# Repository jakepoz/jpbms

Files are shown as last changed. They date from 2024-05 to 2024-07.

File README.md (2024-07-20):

**JPBms**

JPBms is a simple BMS for solar charging and balancing a 3-cell lithium ion battery.

The key thing about it is that it uses no custom ICs, beyond a basic microcontroller. 
That is to say that it depends on no hard-to-find custom ICs that will be obsolete 3 years from now.
It implements a basic charging circuit that can charge a ~12V 3S battery from basically any input power source between
6V-24V, including if that source is a solar panel.

-------------------------------



[v1.3 Schematics](JPBms2-v1.3.pdf)

-----------------------------
- STM32L053 microcontroller
- It's just an inductor with a full set of switches on it, so you can customize it
- Simple resistive balancing
- Single layer board design for easy JLCPCB style production
  - ~$150 to order 5 from JLCPCB, way cheaper in bulk
- Low ~100uA quiescent current
- XT30 solar panel connector, JST-XH battery balance connector

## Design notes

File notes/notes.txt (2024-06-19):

Version 1.3 stuff:
 - The 10M pullup calculation was clearly wrong, voltage only gets up to around 1.25V out of 2.5, so not above the .7 Vdd it should be to be reliable.
   Do I even need the pullup, what's the leakage on the internal one? Better do some real measurements and find out
 - I should have specced 0.5% resistors on the VBATT stuff, or something more precise there in general...

Gate bounce:
 - I'm seeing this effect where, I charge up the inductor via VSolar (off of power supply for now)
 - There is definitely current in the inductor, because then I briefly enable VBatt + GND on the other side, and then turn those gates off again
 - and I see the spike in voltage where the inductor goes just above VBATT charging it
 - but then, the inductor current shrinks, and there is a big osilation.
 - And you see the high side gates of the mosfets take on the same oscillating waveform

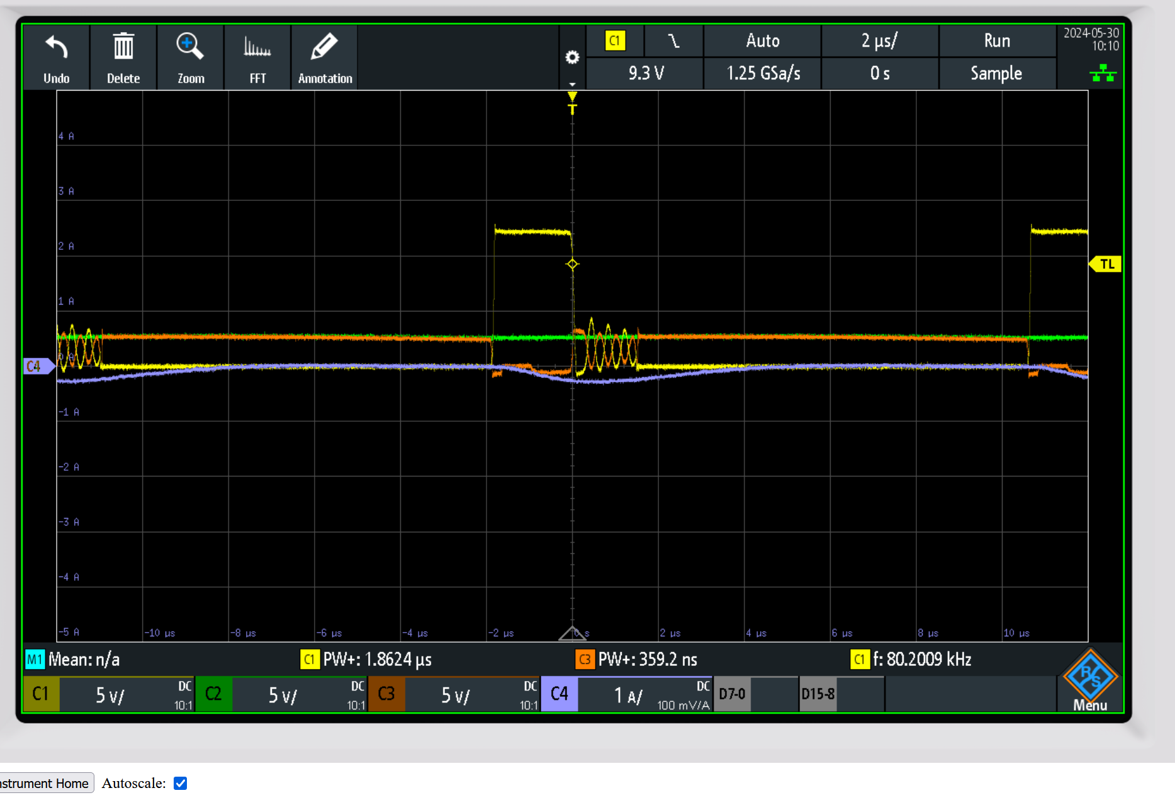
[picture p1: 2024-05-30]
notes/Gate bounce reduced with larger side A time, almost continuous.PNG

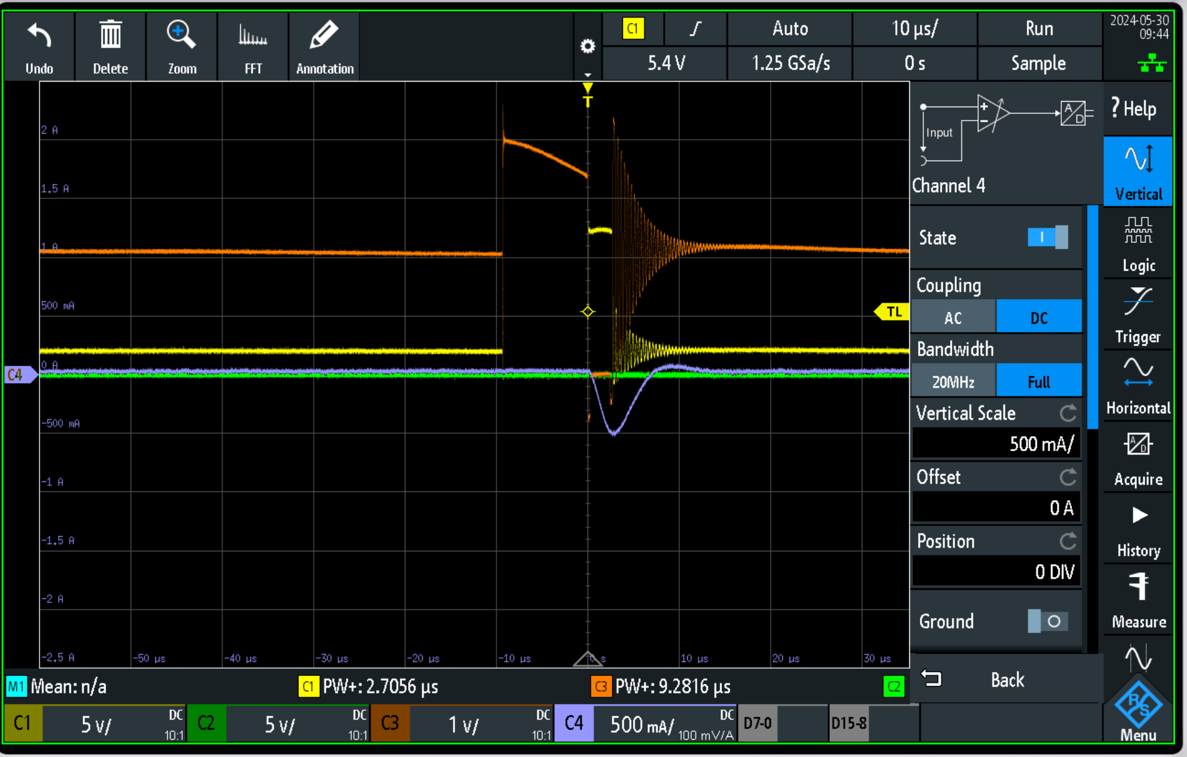
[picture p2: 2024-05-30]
notes/Gate bounce.PNG

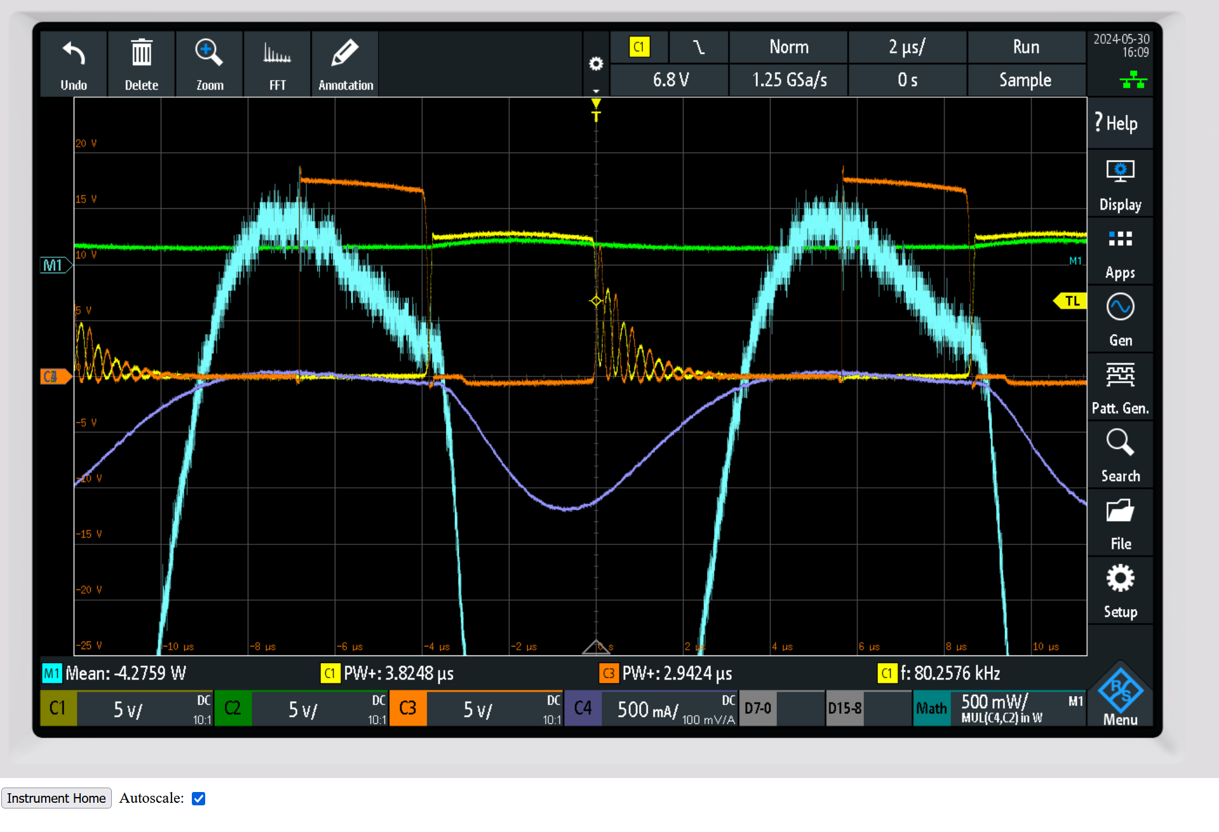
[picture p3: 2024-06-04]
notes/Charging 4.2watts.PNG

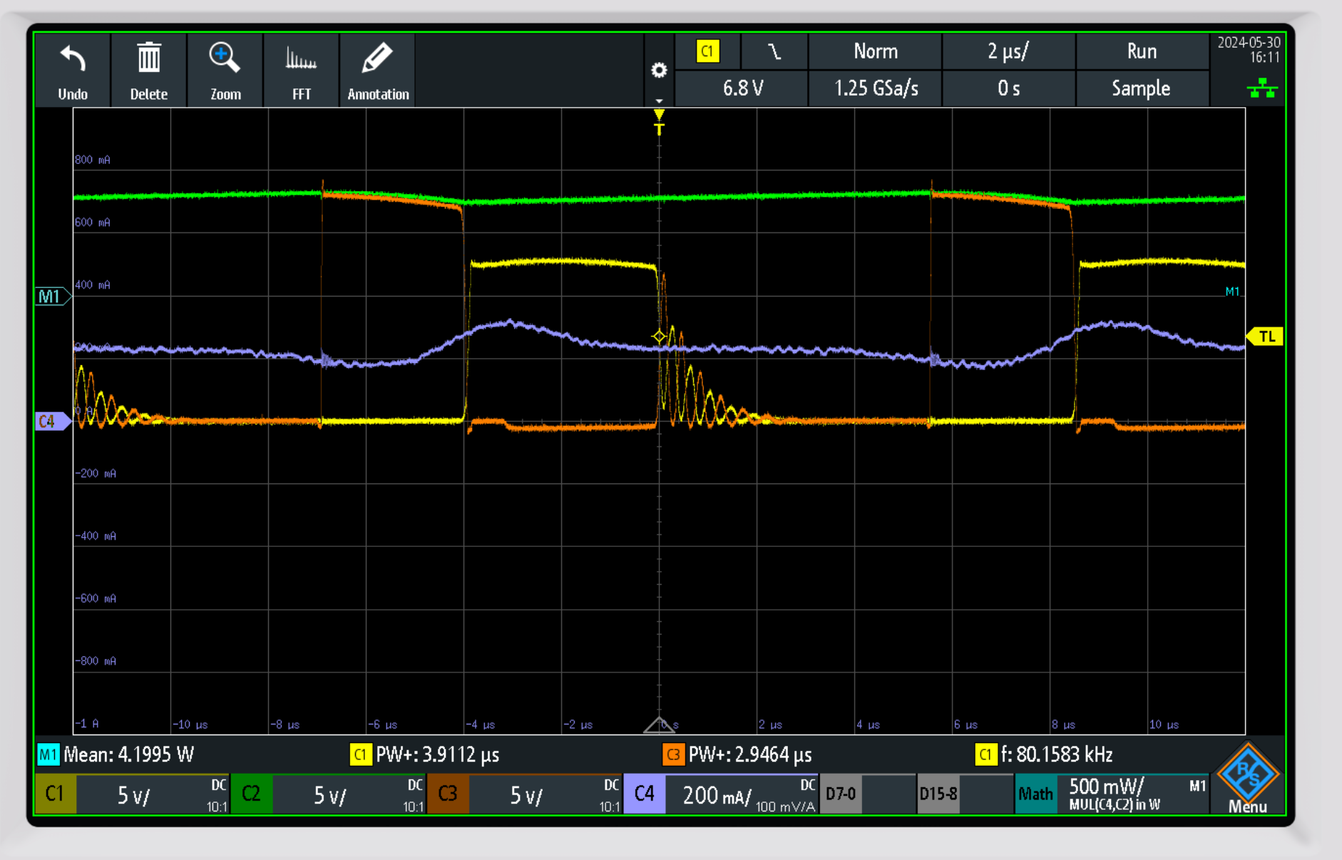
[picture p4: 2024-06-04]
notes/Solar panel current vs voltage.PNG

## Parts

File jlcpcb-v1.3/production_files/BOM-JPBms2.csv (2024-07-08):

Comment | Designator | Footprint | LCSC
LED_G | D4 | LED_0603_1608Metric | C12624
10u | C2,C3,C4,C8 | C_1206_3216Metric | C13585
.1u | C10,C11,C12,C13,C14,C17,C21,C22,C7,C9 | C_0603_1608Metric | C14663
AO3401A | Q21,Q5,Q6,Q7 | SOT-23 | C15127
Conn_01x04 JST-XH | BAL1 | JST_XH_S4B-XH-A_1x04_P2.50mm_Horizontal_Tight | C157925
1u | C15,C16,C19,C20 | C_0603_1608Metric | C15849
10p | C1 | C_0603_1608Metric | C1634
100 | R28,R29,R30 | R_1206_3216Metric | C17901
AO3400A | Q1,Q2,Q3,Q4 | SOT-23 | C20917
1k | R22,R23,R24,R33,R46,R50,R53 | R_0603_1608Metric | C21190
LED_R | D6 | LED_0603_1608Metric | C2286
LED_Y | D11,D12,D13,D5 | LED_0603_1608Metric | C2287
1M | R10,R11,R19,R20,R21,R25,R26,R27,R34,R35,R38,R40,R44,R45,R47,R49,R51,R52,R54,R8,R9 | R_0603_1608Metric | C22935
2k | R4 | R_0603_1608Metric | C22975
4.7k | R2,R37 | R_0603_1608Metric | C23162
56k | R36 | R_0603_1608Metric | C23206
Conn_01x04 Picoblade | UART1 | Molex_PicoBlade_53398-0471_1x04-1MP_P1.25mm_Vertical | C234195
L6388E | U4,U6 | SO-8_3.9x4.9mm_P1.27mm | C23921
150 | R12,R13,R14,R31,R32,R41,R42,R43 | R_0402_1005Metric | C25082
18k | R5 | R_0603_1608Metric | C25810
10M | R39 | R_0603_1608Metric | C26097
ST715M25R | U2 | SOT-23-5 | C2832805
0.1 | R3 | R_1206_3216Metric | C2903496
SW_Push | SW1 | SW_Push_1P1T_XKB_TS-1187A | C318884
47uH | L1 | L_Sunlord_MWSA0605S | C408471
3k | R1 | R_0603_1608Metric | C4211
75 | R15,R16,R17,R18,R48,R55,R56 | R_0603_1608Metric | C4275
XT30PW-M | J1 | AMASS_XT30PW-M_1x02_P2.50mm_Horizontal | C431092
SMAJ30CA | D14 | D_SMA | C5249596
7500 | R6 | R_0603_1608Metric | C728597
2N7002 | Q10,Q13,Q16,Q19,Q20,Q8,Q9 | SOT-323_SC-70 | C7420322
H5VL10B | D7,D8 | D_SOD-882 | C7420372
STM32L053R8Tx | U3 | LQFP-64_10x10mm_P0.5mm | C784738
BAT54SW | D1,D18,D2,D3 | SOT-323_SC-70 | C78606
ZXCT1107 | U1 | SOT-23 | C82766
1600 | R7 | R_0603_1608Metric | C861205
47u | C5 | C_1206_3216Metric | C96123
SK2301AW | Q11,Q12,Q14,Q15,Q17,Q18 | SOT-323_SC-70 | C962722
30V 750mA | F1,F2,F3 | Fuse_1206_3216Metric | C976305
+BATT | TP2 | TestPoint_Loop_D2.60mm_Drill1.6mm_Beaded
TestPoint | TP6 | TestPoint_Loop_D2.60mm_Drill1.6mm_Beaded
GND | TP1 | TestPoint_Loop_D2.60mm_Drill1.6mm_Beaded
TestPoint | TP5 | TestPoint_Loop_D2.60mm_Drill1.6mm_Beaded
SMAJ16A | D9 | D_SMA

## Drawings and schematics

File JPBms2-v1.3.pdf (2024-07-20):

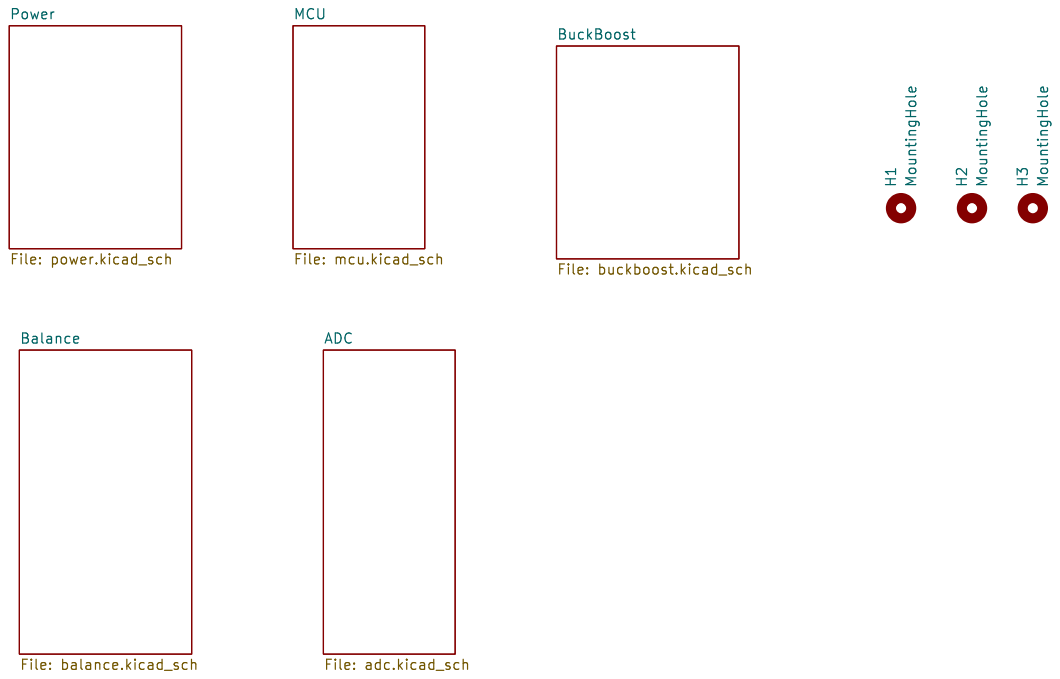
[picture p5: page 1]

Id: 1/6 Title: File: JPBms2.kicad_sch Sheet: /

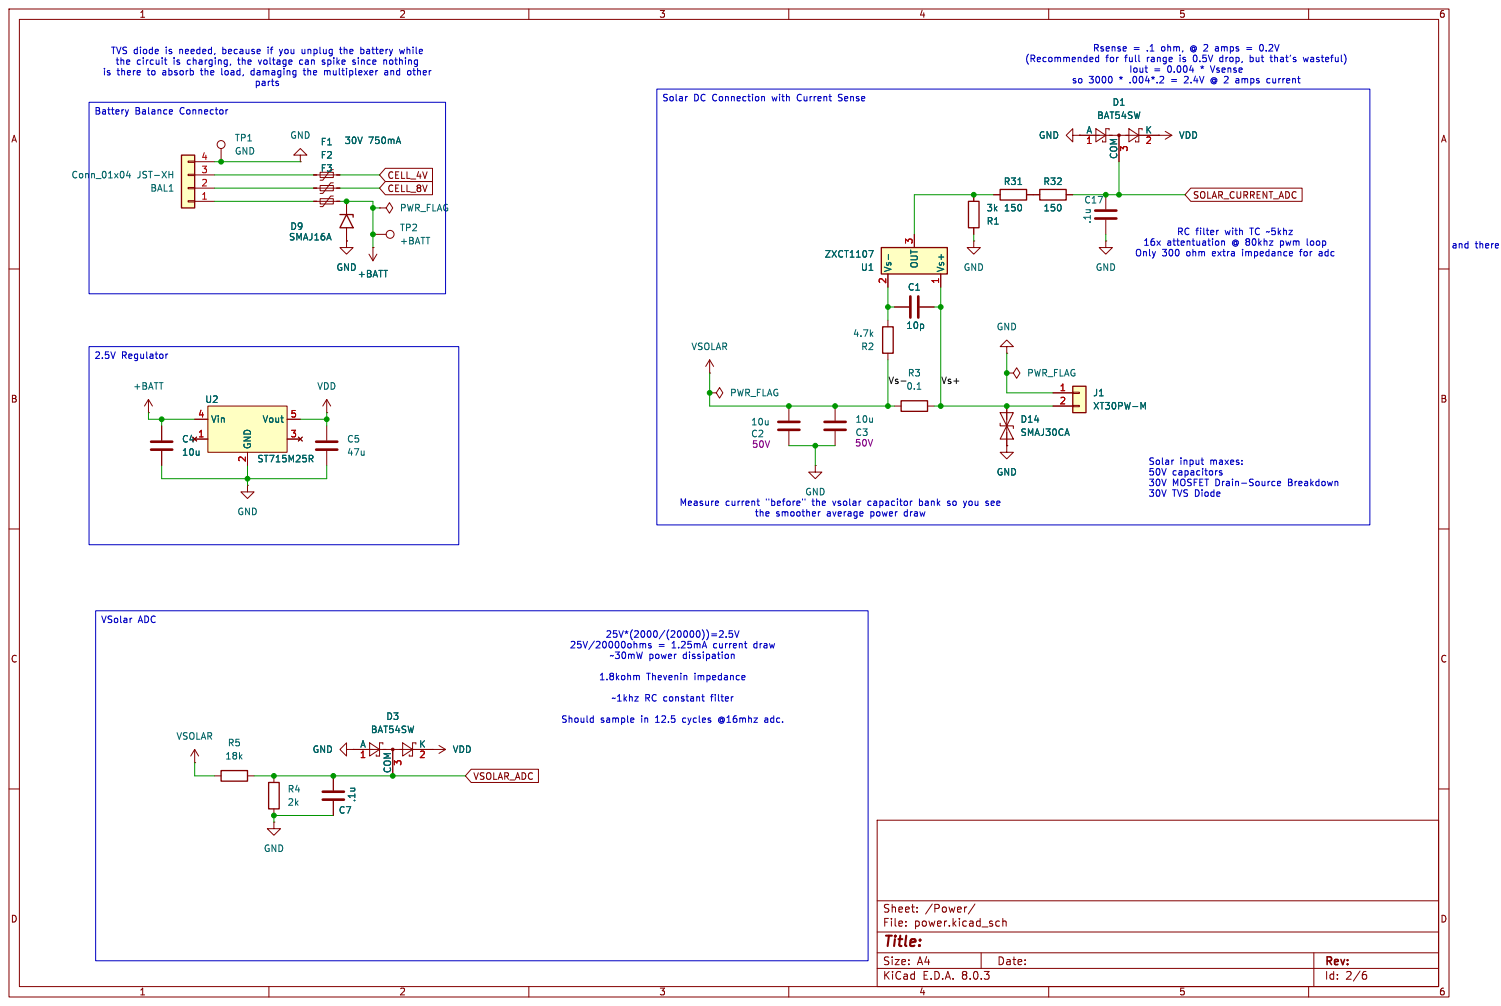
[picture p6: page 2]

Battery Balance Connector 2.5V Regulator VSolar ADC

Id: 2/6 Title: File: power.kicad_sch Sheet: /Power/ R5

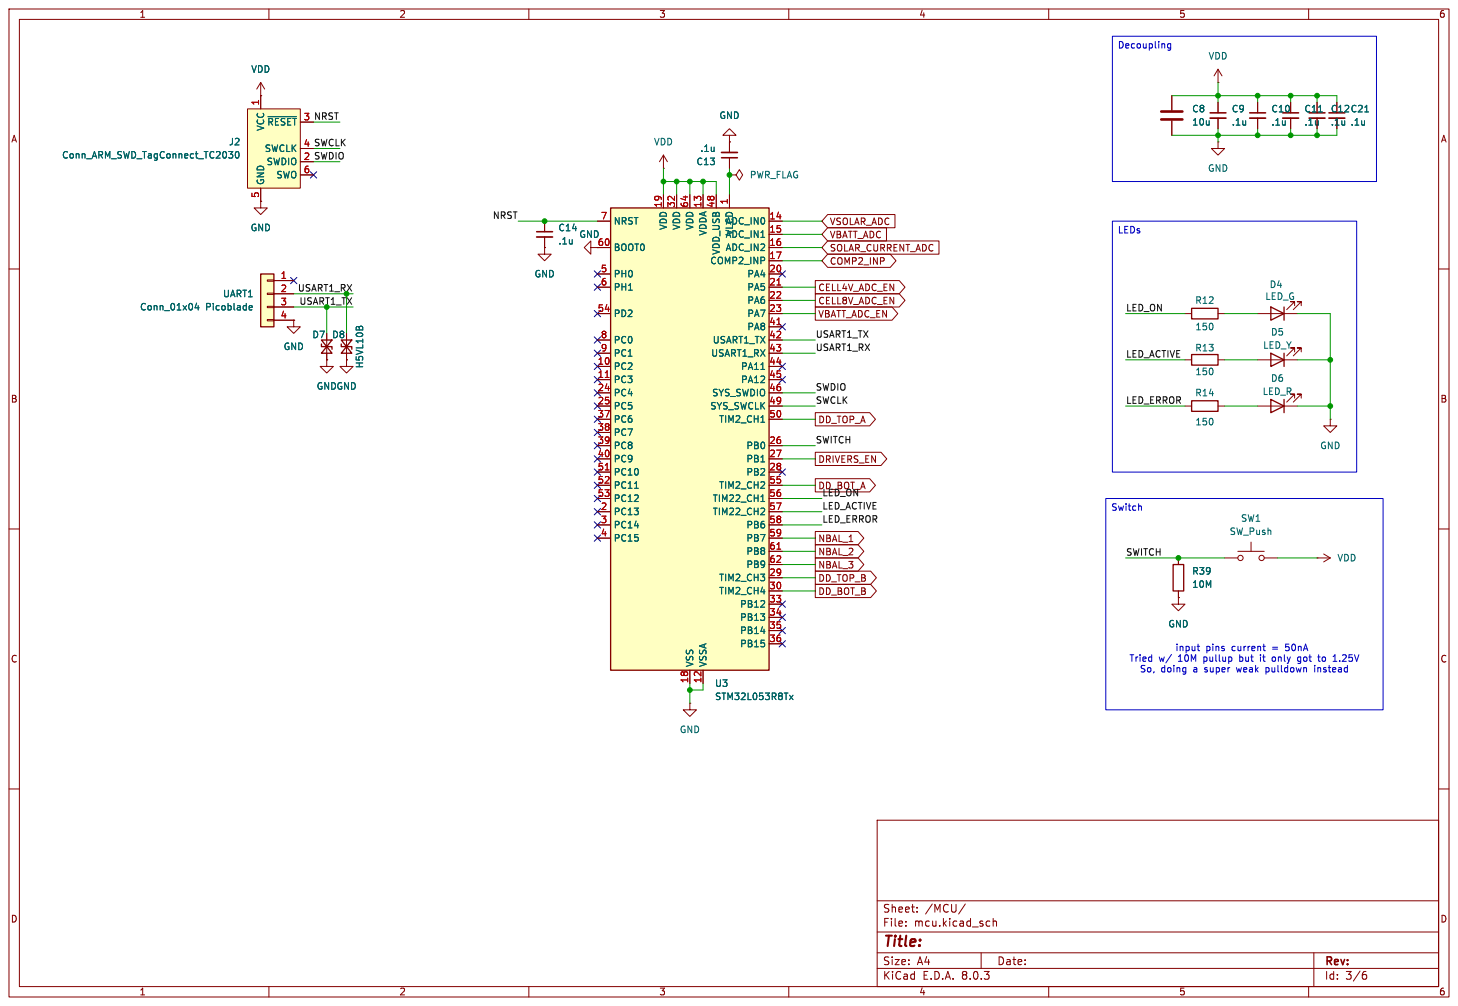
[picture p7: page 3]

1 SWDIO 2 ~{RESET}3 SWCLK 4 GND
LED_R VCC

1 PC2 10 PC3 11 VSSA 12 VDDA 13 ADC_IN0 14 ADC_IN1 15 ADC_IN2 16 COMP2_INP 17 VSS 18 VDD 19 PC13 2 PA4 20 PA5 21 PA6 22 PA7 23 PC4 24 PC5 25 PB0 26 PB1 27 PB2 28 TIM2_CH3 29 PC14 3 TIM2_CH4 30 VDD 32 PB12 33 PB13 34 PB14 35 PB15 36 PC6 37 PC7 38 PC8 39 PC15 4 PC9 40 PA8 41 USART1_TX 42 USART1_RX 43 PA11 44 PA12 45 SYS_SWDIO 46 VDD_USB 48 SYS_SWCLK 49 PH0 5 TIM2_CH1 50 PC10 51 PC11 52 PC12 53 PD2 54 TIM2_CH2 55 TIM22_CH1 56 TIM22_CH2 57 PB6 58 PB7 59 PH1 6 BOOT0 60 PB8 61 PB9 62 VDD 64 NRST 7 PC0 8 PC1 9 C10

1 PC2 10 PC3 11 VSSA 12 VDDA 13 ADC_IN0 14 ADC_IN1 15 ADC_IN2 16 COMP2_INP 17 VSS 18 VDD 19 PC13 2 PA4 20 PA5 21 PA6 22 PA7 23 PC4 24 PC5 25 PB0 26 PB1 27 PB2 28 TIM2_CH3 29 PC14 3 TIM2_CH4 30 VDD 32 PB12 33 PB13 34 PB14 35 PB15 36 PC6 37 PC7 38 PC8 39 PC15 4 PC9 40 PA8 41 USART1_TX 42 USART1_RX 43 PA11 44 PA12 45 SYS_SWDIO 46 VDD_USB 48 SYS_SWCLK 49 PH0 5 TIM2_CH1 50 PC10 51 PC11 52 PC12 53 PD2 54 TIM2_CH2 55 TIM22_CH1 56 TIM22_CH2 57 PB6 58 PB7 59 PH1 6 BOOT0 60 PB8 61 PB9 62 VDD 64 NRST 7 PC0 8 PC1 9 U3STM32L053R8Tx

Tried w/ 10M pullup but it only got to 1.25V

Id: 3/6 Title: File: mcu.kicad_sch Sheet: /MCU/

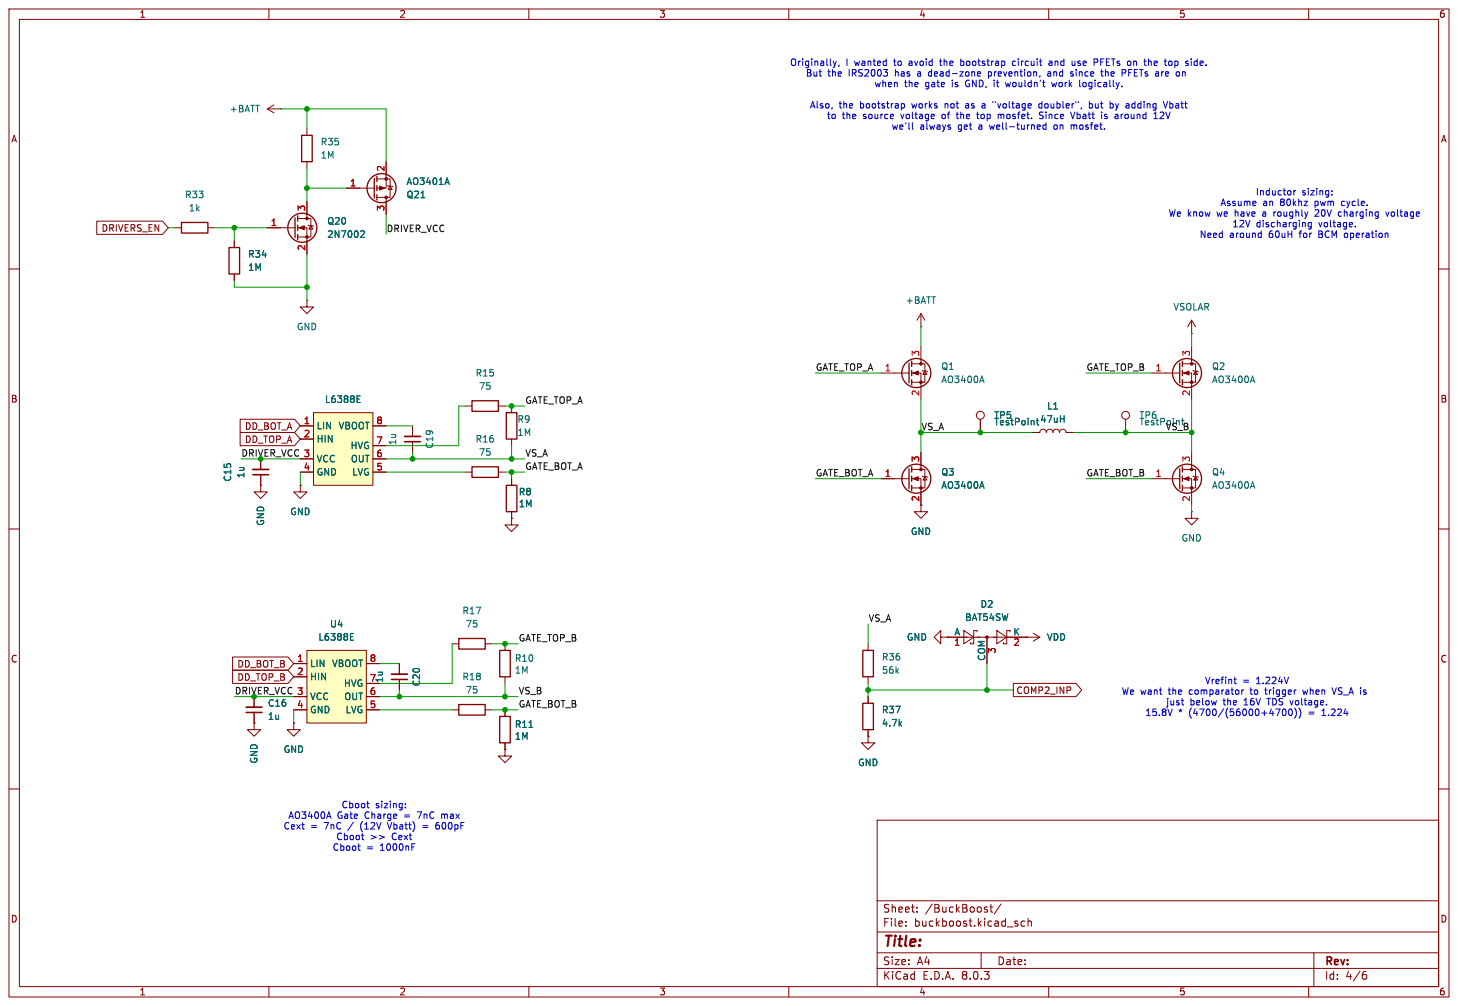
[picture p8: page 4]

Id: 4/6 Title: File: buckboost.kicad_sch Sheet: /BuckBoost/ R11

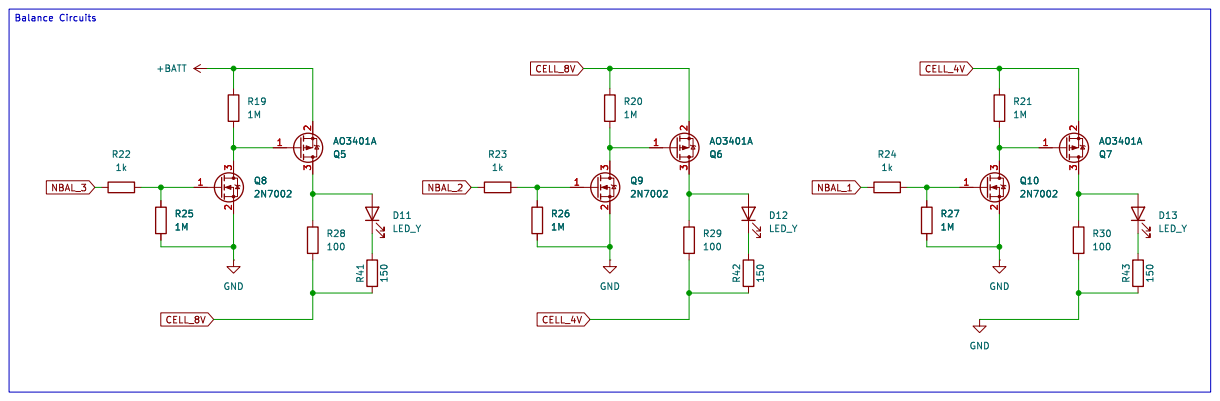
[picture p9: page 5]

Id: 5/6 Title: File: balance.kicad_sch Sheet: /Balance/

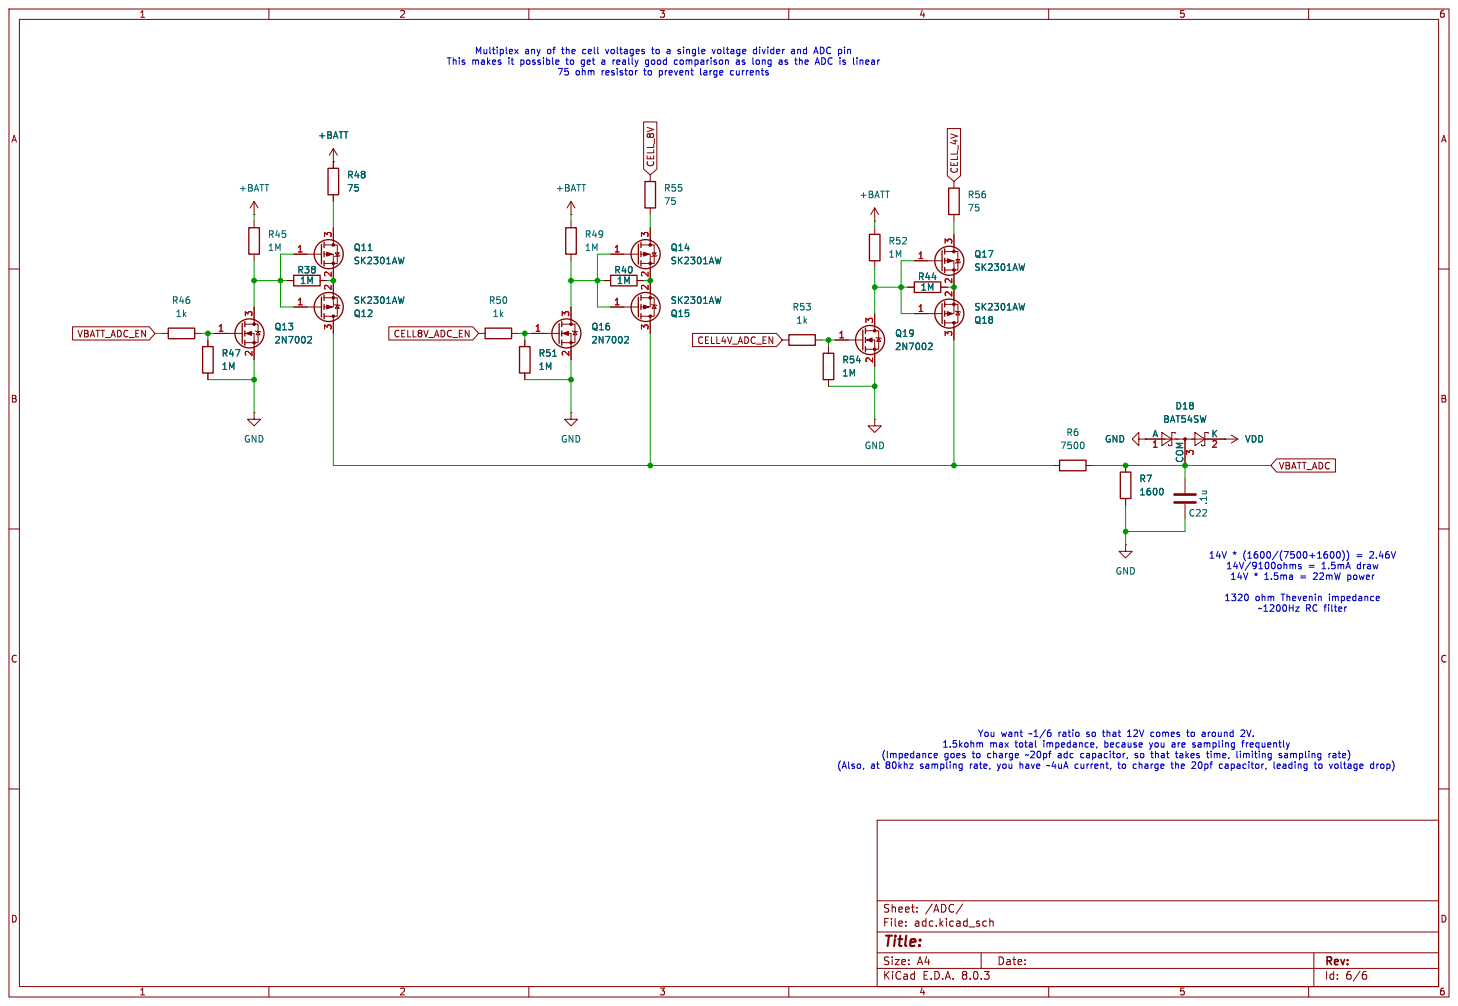
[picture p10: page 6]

Id: 6/6 Title: File: adc.kicad_sch Sheet: /ADC/

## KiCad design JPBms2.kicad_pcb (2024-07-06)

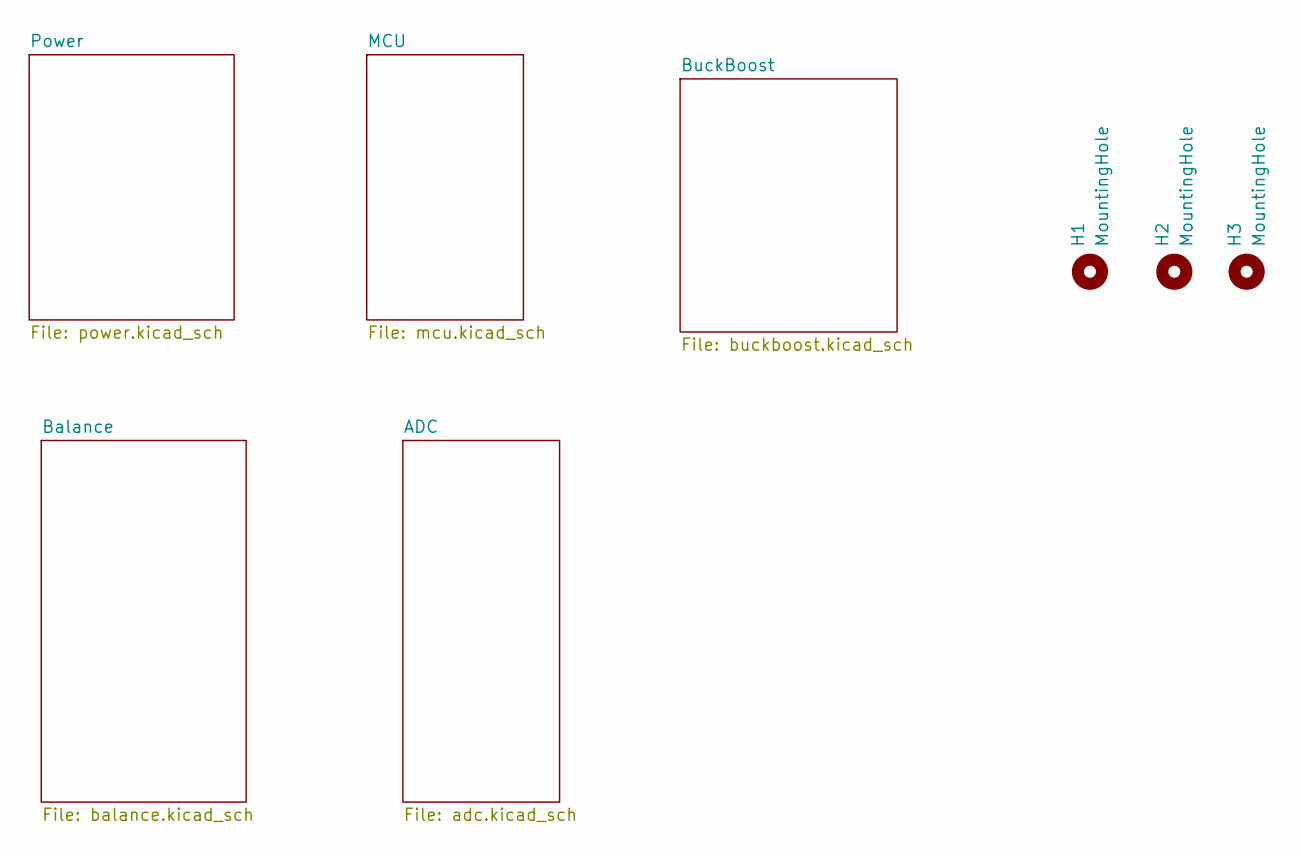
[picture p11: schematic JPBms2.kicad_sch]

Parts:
H1, H2, H3: MountingHole; MountingHole_3.2mm_M3

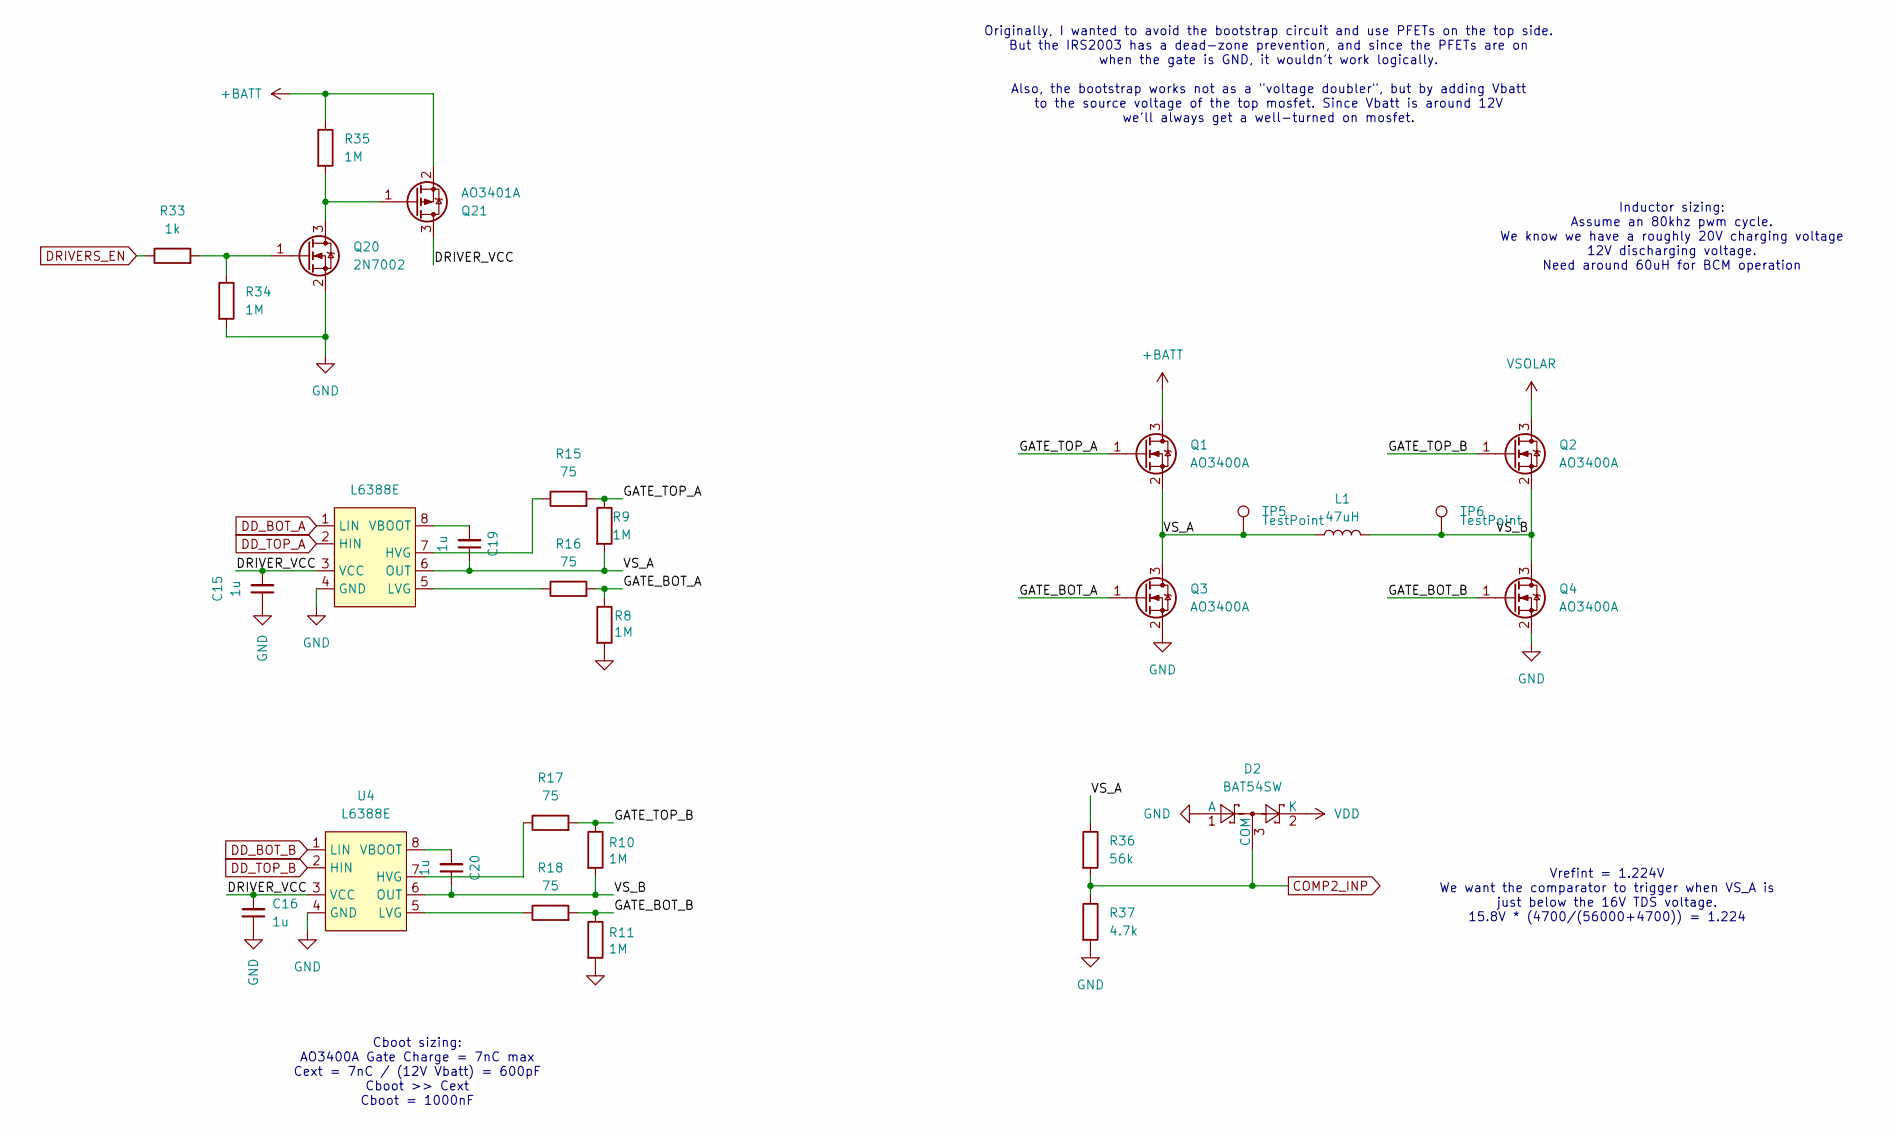
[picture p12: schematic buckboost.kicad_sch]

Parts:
C15, C16, C19, C20: 1u; C_0603_1608Metric; LCSC_Code C15849
D2: BAT54SW; SOT-323_SC-70; LCSC_Code C78606
L1: 47uH; L_Sunlord_MWSA0605S; LCSC_Code C408471
Q1, Q2, Q3, Q4: AO3400A; SOT-23; LCSC_Code C20917
Q20: 2N7002; SOT-323_SC-70; LCSC_Code C7420322
Q21: AO3401A; SOT-23; LCSC_Code C15127
R8, R9, R10, R11, R34, R35: 1M; R_0603_1608Metric; LCSC_Code C22935
R15, R16, R17, R18: 75; R_0603_1608Metric; LCSC_Code C4275
R33: 1k; R_0603_1608Metric; LCSC_Code C21190
R36: 56k; R_0603_1608Metric; LCSC_Code C23206
R37: 4.7k; R_0603_1608Metric; LCSC_Code C23162
TP5, TP6: TestPoint; TestPoint_Loop_D2.60mm_Drill1.6mm_Beaded
U4, U6: L6388E; SO-8_3.9x4.9mm_P1.27mm; LCSC_Code C23921

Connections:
+BATT: Q1.3 (D), Q21.2 (S), R35.1; also elsewhere on the board
/BuckBoost/DRIVER_VCC: C15.2, C16.2, Q21.3 (D), U4.3 (VCC), U6.3 (VCC)
/BuckBoost/GATE_BOT_A: Q3.1 (G), R8.1, R16.2
/BuckBoost/GATE_BOT_B: Q4.1 (G), R11.1, R18.2
/BuckBoost/GATE_TOP_A: Q1.1 (G), R9.1, R15.2
/BuckBoost/GATE_TOP_B: Q2.1 (G), R10.1, R17.2
/BuckBoost/VS_A: C19.1, L1.1, Q1.2 (S), Q3.3 (D), R9.2, R36.1, TP5.1, U6.6 (OUT)
/BuckBoost/VS_B: C20.1, L1.2, Q2.2 (S), Q4.3 (D), R10.2, TP6.1, U4.6 (OUT)
COMP2_INP: D2.3 (COM), R36.2, R37.1; also elsewhere on the board
DD_BOT_A: U6.1 (LIN); also elsewhere on the board
DD_BOT_B: U4.1 (LIN); also elsewhere on the board
DD_TOP_A: U6.2 (HIN); also elsewhere on the board
DD_TOP_B: U4.2 (HIN); also elsewhere on the board
DRIVERS_EN: R33.1; also elsewhere on the board
GND: C15.1, C16.1, D2.1 (A), Q3.2 (S), Q4.2 (S), Q20.2 (S), R8.2, R11.2, R34.2, R37.2, U4.4 (GND), U6.4 (GND); also elsewhere on the board
unnamed: Q20.3 (D), Q21.1 (G), R35.2
unnamed: Q20.1 (G), R33.2, R34.1
unnamed: R17.1, U4.7 (HVG)
unnamed: R18.1, U4.5 (LVG)
unnamed: C20.2, U4.8 (VBOOT)
unnamed: R15.1, U6.7 (HVG)
unnamed: R16.1, U6.5 (LVG)
unnamed: C19.2, U6.8 (VBOOT)
VDD: D2.2 (K); also elsewhere on the board
VSOLAR: Q2.3 (D); also elsewhere on the board

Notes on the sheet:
Inductor sizing: Assume an 80khz pwm cycle. We know we have a roughly 20V charging voltage 12V discharging voltage. Need around 60uH for BCM operation
Cboot sizing: AO3400A Gate Charge = 7nC max Cext = 7nC / (12V Vbatt) = 600pF Cboot >> Cext Cboot = 1000nF
Vrefint = 1.224V We want the comparator to trigger when VS_A is just below the 16V TDS voltage. 15.8V * (4700/(56000+4700)) = 1.224
Originally, I wanted to avoid the bootstrap circuit and use PFETs on the top side. But the IRS2003 has a dead-zone prevention, and since the PFETs are on when the gate is GND, it wouldn't work logically. Also, the bootstrap works not as a "voltage doubler", but by adding Vbatt to the source voltage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

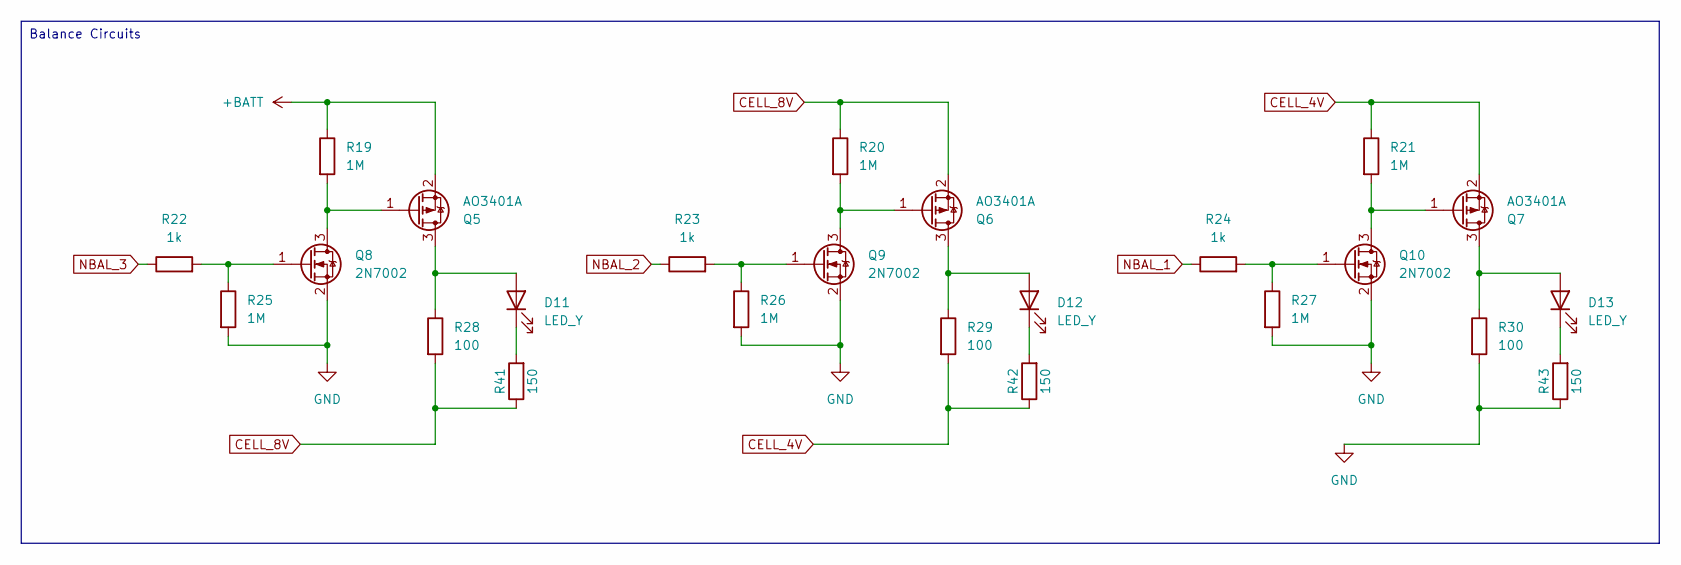
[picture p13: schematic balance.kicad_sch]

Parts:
D11, D12, D13: LED_Y; LED_0603_1608Metric; LCSC_Code C2287
Q5, Q6, Q7: AO3401A; SOT-23; LCSC_Code C15127
Q8, Q9, Q10: 2N7002; SOT-323_SC-70; LCSC_Code C7420322
R19, R20, R21, R25, R26, R27: 1M; R_0603_1608Metric; LCSC_Code C22935
R22, R23, R24: 1k; R_0603_1608Metric; LCSC_Code C21190
R28, R29, R30: 100; R_1206_3216Metric; LCSC_Code C17901
R41, R42, R43: 150; R_0402_1005Metric; LCSC_Code C25082

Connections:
+BATT: Q5.2 (S), R19.1; also elsewhere on the board
CELL_4V: Q7.2 (S), R21.1, R29.2, R42.1; also elsewhere on the board
CELL_8V: Q6.2 (S), R20.1, R28.2, R41.1; also elsewhere on the board
GND: Q8.2 (S), Q9.2 (S), Q10.2 (S), R25.2, R26.2, R27.2, R30.2, R43.1; also elsewhere on the board
NBAL_1: R24.1; also elsewhere on the board
NBAL_2: R23.1; also elsewhere on the board
NBAL_3: R22.1; also elsewhere on the board
unnamed: D11.2 (A), Q5.3 (D), R28.1
unnamed: D11.1 (K), R41.2
unnamed: D12.2 (A), Q6.3 (D), R29.1
unnamed: D12.1 (K), R42.2
unnamed: D13.2 (A), Q7.3 (D), R30.1
unnamed: D13.1 (K), R43.2
unnamed: Q5.1 (G), Q8.3 (D), R19.2
unnamed: Q6.1 (G), Q9.3 (D), R20.2
unnamed: Q8.1 (G), R22.2, R25.1
unnamed: Q9.1 (G), R23.2, R26.1
unnamed: Q7.1 (G), Q10.3 (D), R21.2
unnamed: Q10.1 (G), R24.2, R27.1

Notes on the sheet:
Balance Circuits

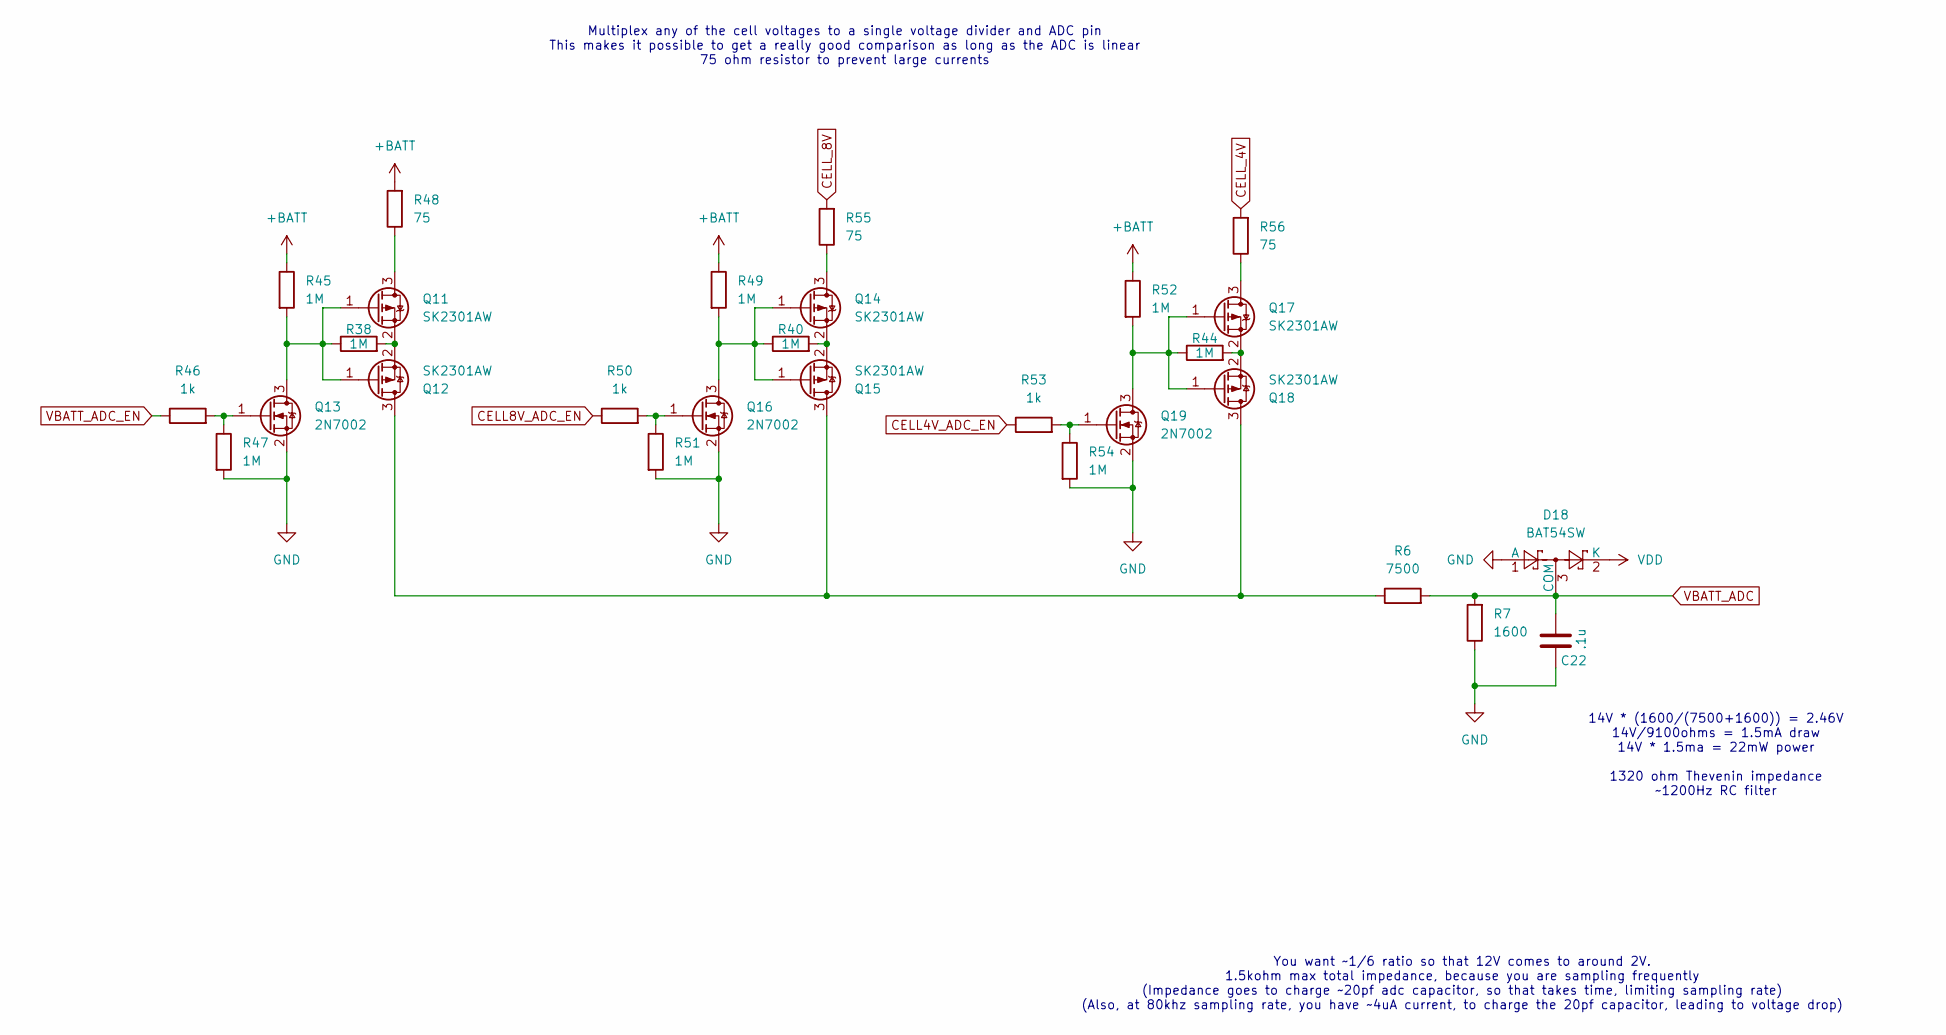
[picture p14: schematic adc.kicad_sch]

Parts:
C22: .1u; C_0603_1608Metric; LCSC_Code C14663
D18: BAT54SW; SOT-323_SC-70; LCSC_Code C78606
Q11, Q12, Q14, Q15, Q17, Q18: SK2301AW; SOT-323_SC-70; LCSC_Code C962722
Q13, Q16, Q19: 2N7002; SOT-323_SC-70; LCSC_Code C7420322
R6: 7500; R_0603_1608Metric; LCSC_Code C728597
R7: 1600; R_0603_1608Metric; LCSC_Code C861205
R38, R40, R44, R45, R47, R49, R51, R52, R54: 1M; R_0603_1608Metric; LCSC_Code C22935
R46, R50, R53: 1k; R_0603_1608Metric; LCSC_Code C21190
R48, R55, R56: 75; R_0603_1608Metric; LCSC_Code C4275

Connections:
+BATT: R45.1, R48.2, R49.1, R52.1; also elsewhere on the board
CELL4V_ADC_EN: R53.1; also elsewhere on the board
CELL8V_ADC_EN: R50.1; also elsewhere on the board
CELL_4V: R56.2; also elsewhere on the board
CELL_8V: R55.2; also elsewhere on the board
GND: C22.2, D18.1 (A), Q13.2 (S), Q16.2 (S), Q19.2 (S), R7.1, R47.2, R51.2, R54.2; also elsewhere on the board
unnamed: Q11.3 (D), R48.1
unnamed: Q11.1 (G), Q12.1 (G), Q13.3 (D), R38.1, R45.2
unnamed: Q11.2 (S), Q12.2 (S), R38.2
unnamed: Q12.3 (D), Q15.3 (D), Q18.3 (D), R6.1
unnamed: Q13.1 (G), R46.2, R47.1
unnamed: Q14.3 (D), R55.1
unnamed: Q14.1 (G), Q15.1 (G), Q16.3 (D), R40.1, R49.2
unnamed: Q14.2 (S), Q15.2 (S), R40.2
unnamed: Q16.1 (G), R50.2, R51.1
unnamed: Q17.3 (D), R56.1
unnamed: Q17.1 (G), Q18.1 (G), Q19.3 (D), R44.1, R52.2
unnamed: Q17.2 (S), Q18.2 (S), R44.2
unnamed: Q19.1 (G), R53.2, R54.1
VBATT_ADC: C22.1, D18.3 (COM), R6.2, R7.2; also elsewhere on the board
VBATT_ADC_EN: R46.1; also elsewhere on the board
VDD: D18.2 (K); also elsewhere on the board

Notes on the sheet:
You want ~1/6 ratio so that 12V comes to around 2V. 1.5kohm max total impedance, because you are sampling frequently (Impedance goes to charge ~20pf adc capacitor, so that takes time, limiting sampling rate) (Also, at 80khz sampling rate, you have ~4uA current, to charge the 20pf capacitor, leading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
14V * (1600/(7500+1600)) = 2.46V 14V/9100ohms = 1.5mA draw 14V * 1.5ma = 22mW power 1320 ohm Thevenin impedance ~1200Hz RC filter
Multiplex any of the cell voltages to a single voltage divider and ADC pin This makes it possible to get a really good comparison as long as the ADC is linear 75 ohm resistor to prevent large currents

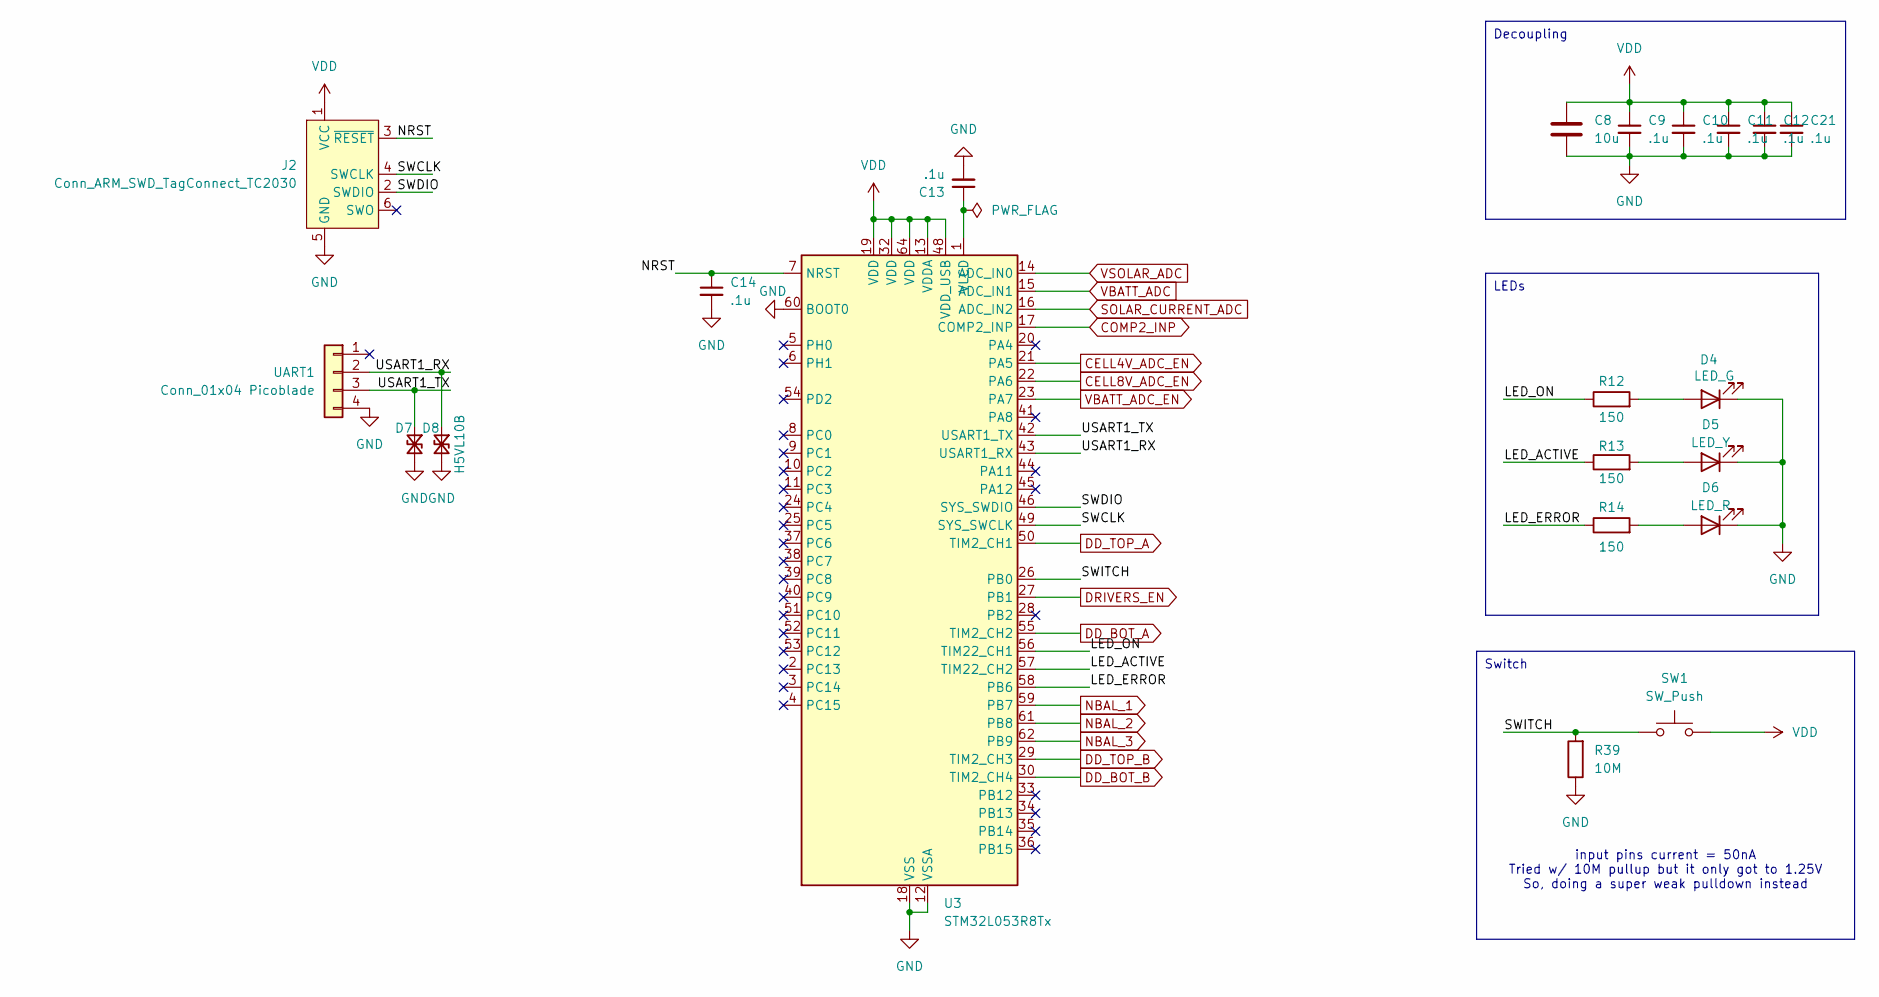
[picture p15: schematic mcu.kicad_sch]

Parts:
C8: 10u; C_1206_3216Metric; LCSC_Code C13585
C9, C10, C11, C12, C13, C14, C21: .1u; C_0603_1608Metric; LCSC_Code C14663
D4: LED_G; LED_0603_1608Metric; LCSC_Code C12624
D5: LED_Y; LED_0603_1608Metric; LCSC_Code C2287
D6: LED_R; LED_0603_1608Metric; LCSC_Code C2286
D7, D8: H5VL10B; D_SOD-882; LCSC_Code C7420372
J2: Conn_ARM_SWD_TagConnect_TC2030; Tag-Connect_TC2030-IDC-FP_2x03_P1.27mm_Vertical
R12, R13, R14: 150; R_0402_1005Metric; LCSC_Code C25082
R39: 10M; R_0603_1608Metric; LCSC_Code C26097
SW1: SW_Push; SW_Push_1P1T_XKB_TS-1187A; LCSC_Code C318884
U3: STM32L053R8Tx; LQFP-64_10x10mm_P0.5mm
UART1: Conn_01x04 Picoblade; Molex_PicoBlade_53398-0471_1x04-1MP_P1.25mm_Vertical; LCSC_Code C234195

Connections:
/MCU/LED_ACTIVE: R13.1, U3.57 (TIM22_CH2)
/MCU/LED_ERROR: R14.1, U3.58 (PB6)
/MCU/LED_ON: R12.1, U3.56 (TIM22_CH1)
/MCU/NRST: C14.1, J2.3 (~RESET), U3.7 (NRST)
/MCU/SWCLK: J2.4 (SWCLK), U3.49 (SYS_SWCLK)
/MCU/SWDIO: J2.2 (SWDIO), U3.46 (SYS_SWDIO)
/MCU/SWITCH: R39.2, SW1.1, U3.26 (PB0)
/MCU/USART1_RX: D8.1 (A1), U3.43 (USART1_RX), UART1.2
/MCU/USART1_TX: D7.1 (A1), U3.42 (USART1_TX), UART1.3
CELL4V_ADC_EN: U3.21 (PA5); also elsewhere on the board
CELL8V_ADC_EN: U3.22 (PA6); also elsewhere on the board
COMP2_INP: U3.17 (COMP2_INP); also elsewhere on the board
DD_BOT_A: U3.55 (TIM2_CH2); also elsewhere on the board
DD_BOT_B: U3.30 (TIM2_CH4); also elsewhere on the board
DD_TOP_A: U3.50 (TIM2_CH1); also elsewhere on the board
DD_TOP_B: U3.29 (TIM2_CH3); also elsewhere on the board
DRIVERS_EN: U3.27 (PB1); also elsewhere on the board
GND: C8.2, C9.2, C10.2, C11.2, C12.2, C13.2, C14.2, C21.2, D4.1 (K), D5.1 (K), D6.1 (K), D7.2 (A2), D8.2 (A2), J2.5 (GND), R39.1, U3.12 (VSSA), U3.18 (VSS), U3.31 (VSS), U3.47 (VSS), U3.60 (BOOT0), U3.63 (VSS), UART1.4; also elsewhere on the board
NBAL_1: U3.59 (PB7); also elsewhere on the board
NBAL_2: U3.61 (PB8); also elsewhere on the board
NBAL_3: U3.62 (PB9); also elsewhere on the board
unnamed: D4.2 (A), R12.2
unnamed: D5.2 (A), R13.2
unnamed: D6.2 (A), R14.2
unnamed: C13.1, U3.1 (VLCD)
SOLAR_CURRENT_ADC: U3.16 (ADC_IN2); also elsewhere on the board
VBATT_ADC: U3.15 (ADC_IN1); also elsewhere on the board
VBATT_ADC_EN: U3.23 (PA7); also elsewhere on the board
VDD: C8.1, C9.1, C10.1, C11.1, C12.1, C21.1, J2.1 (VCC), SW1.2, U3.13 (VDDA), U3.19 (VDD), U3.32 (VDD), U3.48 (VDD_USB), U3.64 (VDD); also elsewhere on the board
VSOLAR_ADC: U3.14 (ADC_IN0); also elsewhere on the board

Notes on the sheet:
Decoupling
LEDs
Switch
input pins current = 50nA Tried w/ 10M pullup but it only got to 1.25V So, doing a super weak pulldown instead

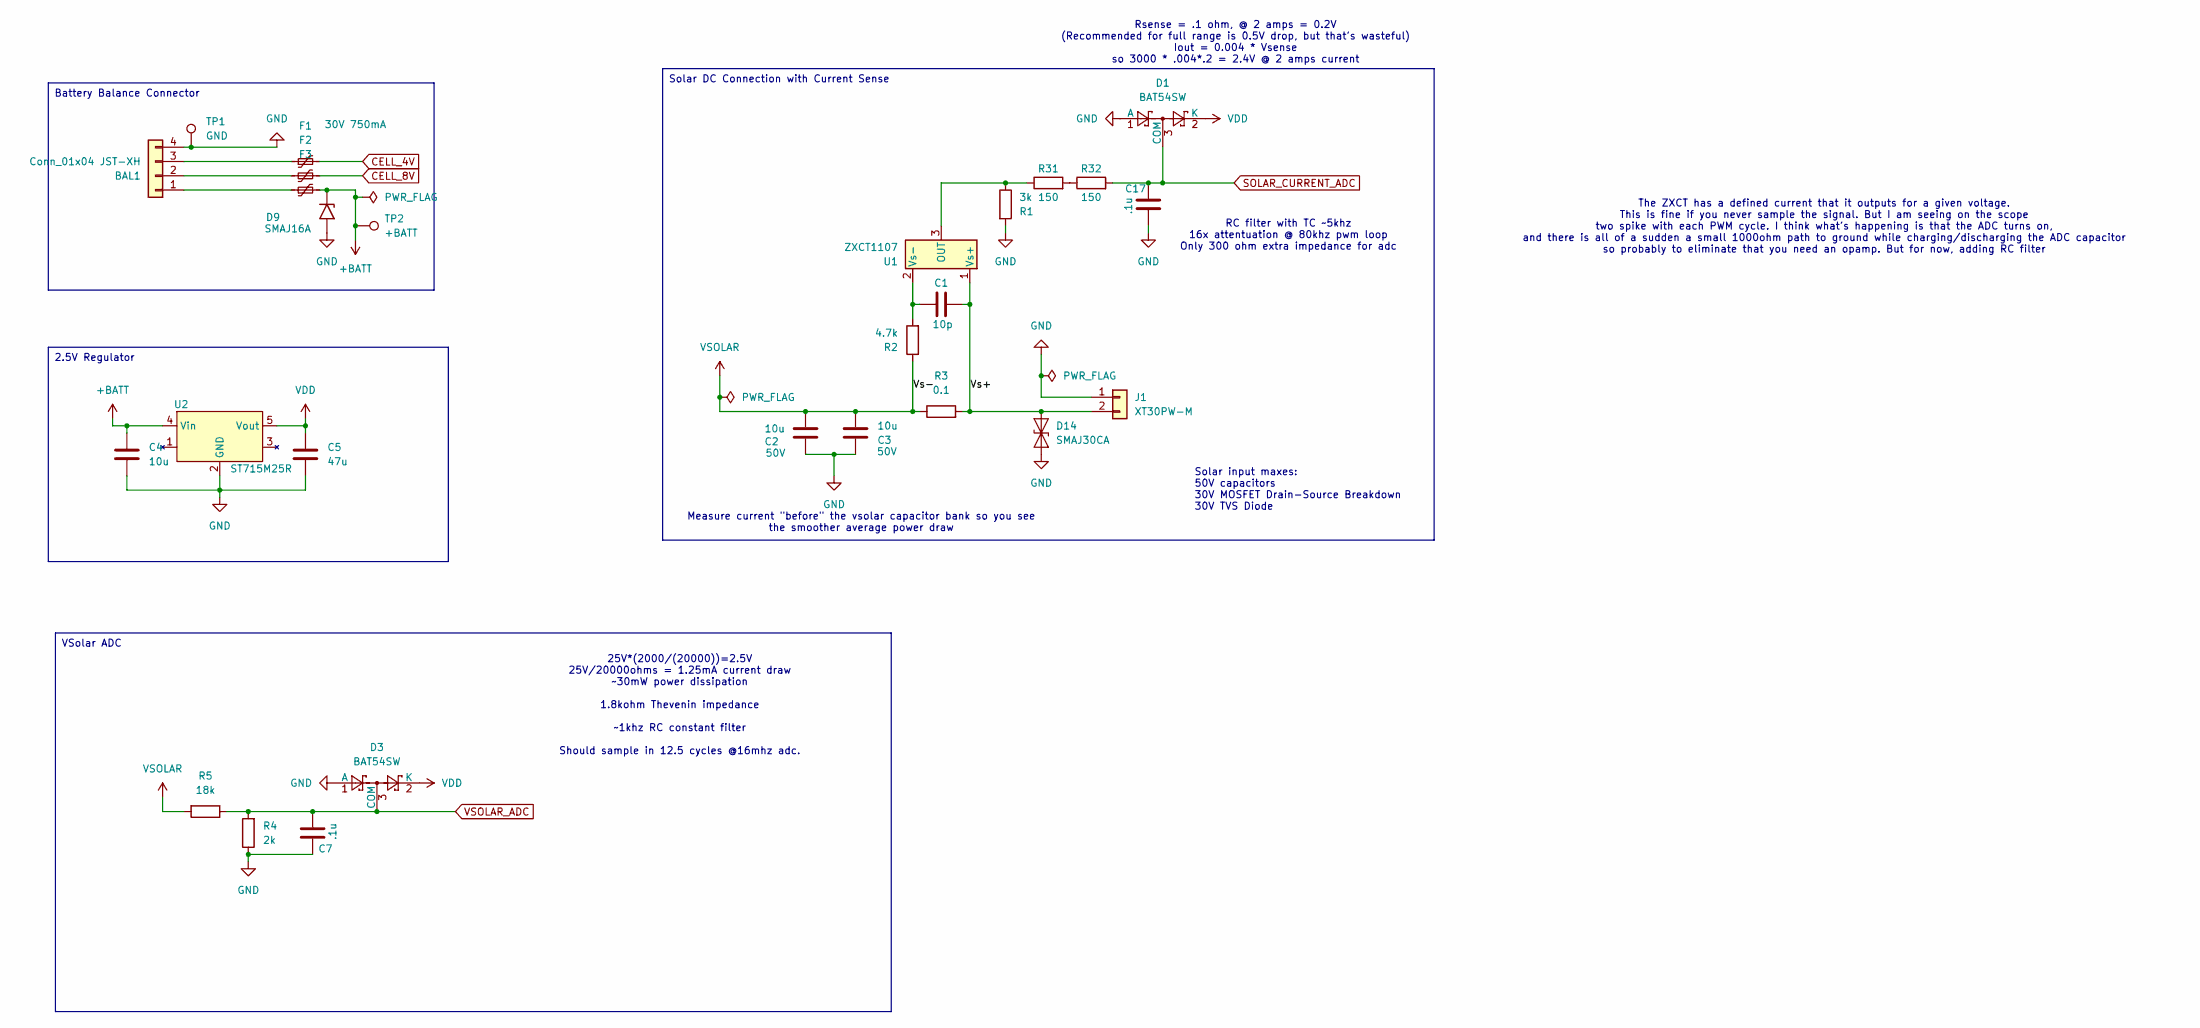
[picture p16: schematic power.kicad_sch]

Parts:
BAL1: Conn_01x04 JST-XH; JST_XH_S4B-XH-A_1x04_P2.50mm_Horizontal_Tight; LCSC_Code C157925
C1: 10p; C_0603_1608Metric; LCSC_Code C1634
C2, C3: 10u; C_1206_3216Metric; Voltage 50V; LCSC_Code C13585
C4: 10u; C_1206_3216Metric; LCSC_Code C13585
C5: 47u; C_1206_3216Metric; LCSC_Code C96123
C7, C17: .1u; C_0603_1608Metric; LCSC_Code C14663
D1, D3: BAT54SW; SOT-323_SC-70; LCSC_Code C78606
D9: SMAJ16A; D_SMA
D14: SMAJ30CA; D_SMA; LCSC_Code C5249596
F1, F2, F3: 30V 750mA; Fuse_1206_3216Metric; LCSC_Code C976305
J1: XT30PW-M; AMASS_XT30PW-M_1x02_P2.50mm_Horizontal; LCSC_Code C431092
R1: 3k; R_0603_1608Metric; LCSC_Code C4211
R2: 4.7k; R_0603_1608Metric; LCSC_Code C23162
R3: 0.1; R_1206_3216Metric; LCSC_Code C2903496
R4: 2k; R_0603_1608Metric; LCSC_Code C22975
R5: 18k; R_0603_1608Metric; LCSC_Code C25810
R31, R32: 150; R_0402_1005Metric; LCSC_Code C25082
TP1: GND; TestPoint_Loop_D2.60mm_Drill1.6mm_Beaded
TP2: +BATT; TestPoint_Loop_D2.60mm_Drill1.6mm_Beaded
U1: ZXCT1107; SOT-23; LCSC_Code C82766
U2: ST715M25R; SOT-23-5; LCSC_Code C2832805

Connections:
+BATT: C4.1, D9.1 (A1), F3.2, TP2.1, U2.4 (Vin); also elsewhere on the board
/Power/Vs+: C1.1, D14.2 (A2), J1.2, R3.2, U1.1 (Vs+)
CELL_4V: F1.2; also elsewhere on the board
CELL_8V: F2.2; also elsewhere on the board
GND: BAL1.4, C2.1, C3.1, C4.2, C5.2, C7.2, C17.1, D1.1 (A), D3.1 (A), D9.2 (A2), D14.1 (A1), J1.1, R1.2, R4.1, TP1.1, U2.2 (GND); also elsewhere on the board
unnamed: BAL1.1, F3.1
unnamed: BAL1.2, F2.1
unnamed: BAL1.3, F1.1
unnamed: R31.2, R32.1
unnamed: R1.1, R31.1, U1.3 (OUT)
unnamed: C1.2, R2.2, U1.2 (Vs-)
SOLAR_CURRENT_ADC: C17.2, D1.3 (COM), R32.2; also elsewhere on the board
VDD: C5.1, D1.2 (K), D3.2 (K), U2.5 (Vout); also elsewhere on the board
VSOLAR: C2.2, C3.2, R2.1, R3.1, R5.2; also elsewhere on the board
VSOLAR_ADC: C7.1, D3.3 (COM), R4.2, R5.1; also elsewhere on the board

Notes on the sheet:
2.5V Regulator
Solar DC Connection with Current Sense
VSolar ADC
Battery Balance Connector
The ZXCT has a defined current that it outputs for a given voltage. This is fine if you never sample the signal. But I am seeing on the scope two spike with each PWM cycle. I think what's happening is that the ADC turns on, and there is all of a sudden a small 1000ohm path to ground while charging/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
Solar input maxes: 50V capacitors 30V MOSFET Drain-Source Breakdown 30V TVS Diode
Measure current "before" the vsolar capacitor bank so you see the smoother average power draw
25V*(2000/(20000))=2.5V 25V/20000ohms = 1.25mA current draw ~30mW power dissipation 1.8kohm Thevenin impedance ~1khz RC constant filter Should sample in 12.5 cycles @16mhz adc.
RC filter with TC ~5khz 16x attentuation @ 80khz pwm loop Only 300 ohm extra impedance for adc
Rsense = .1 ohm, @ 2 amps = 0.2V (Recommended for full range is 0.5V drop, but that's wasteful) Iout = 0.004 * Vsense so 3000 * .004*.2 = 2.4V @ 2 amps current

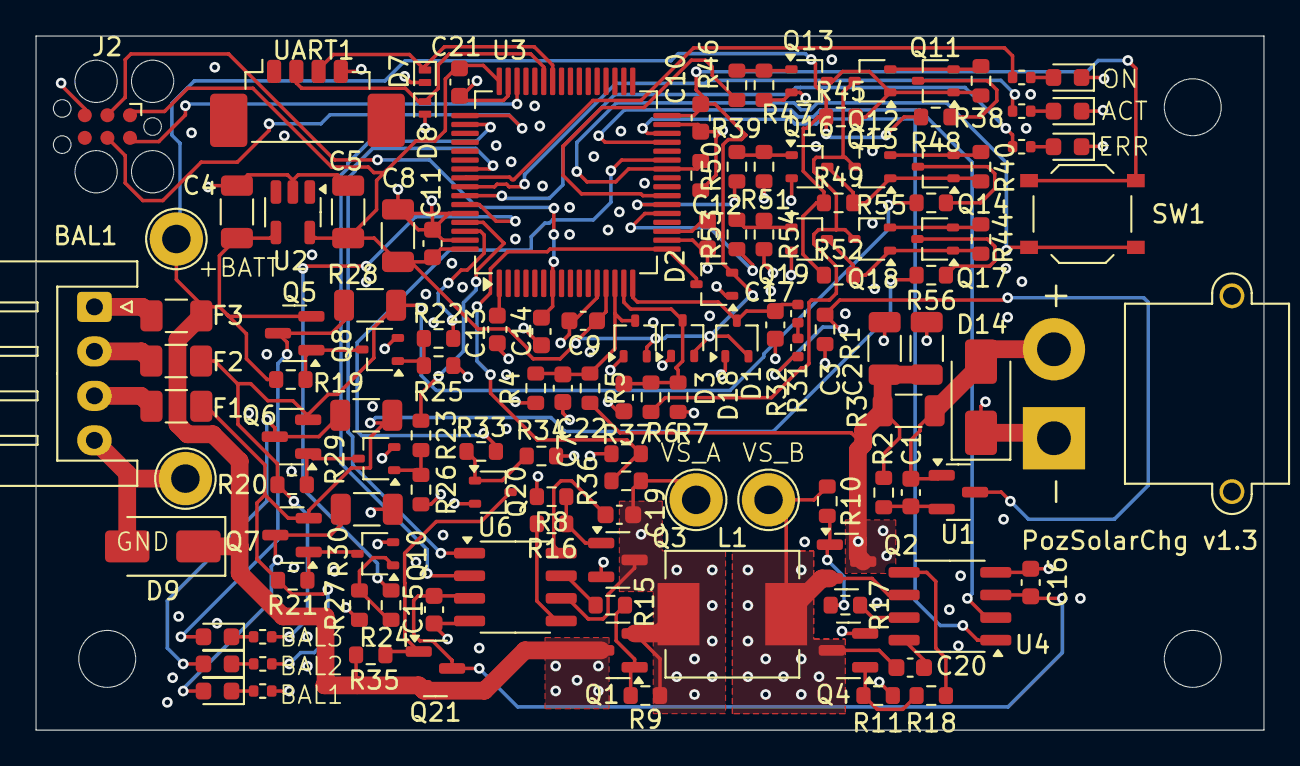
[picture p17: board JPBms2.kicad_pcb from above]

Board: 4 copper layers, 69.0 x 39.0 mm, 132 parts (0 on the bottom side), 81 nets.

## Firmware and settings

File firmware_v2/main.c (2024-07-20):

#include <stdio.h>

#include "pins.h"
#include "config.h"
#include "usart.h"

#include <libopencm3/cm3/scb.h>
#include <libopencm3/cm3/nvic.h>
#include <libopencm3/cm3/systick.h>
#include <libopencm3/cm3/cortex.h> // Include this header for __WFI

#include <libopencm3/stm32/rcc.h>
#include <libopencm3/stm32/flash.h>
#include <libopencm3/stm32/gpio.h>
#include <libopencm3/stm32/pwr.h>
#include <libopencm3/stm32/usart.h>
#include <libopencm3/stm32/timer.h>
#include <libopencm3/stm32/exti.h>
#include <libopencm3/stm32/adc.h>
#include <libopencm3/stm32/dma.h>

#define CLAMP(val, min, max) ((val) < (min) ? (min) : ((val) > (max) ? (max) : (val)))


/*!< Low Frequency Mode enable */
// Must be set with ADC Freq < 3.5Mhz, and we run at 2.1 main clock
#define ADC_CCR_LFMEN                       ((uint32_t)0x02000000U)
#define ADC_CFGR2_TOVS                      ((uint32_t)0x80000200U)     /*!< Triggered Oversampling */
#define ADC_CFGR2_OVSS                      ((uint32_t)0x000001E0U)     /*!< OVSS [3:0] bits (Oversampling shift) */
#define ADC_CFGR2_OVSS_0                    ((uint32_t)0x00000020U)     /*!< Bit 0 */
#define ADC_CFGR2_OVSS_1                    ((uint32_t)0x00000040U)     /*!< Bit 1 */
#define ADC_CFGR2_OVSS_2                    ((uint32_t)0x00000080U)     /*!< Bit 2 */
#define ADC_CFGR2_OVSS_3                    ((uint32_t)0x00000100U)     /*!< Bit 3 */
#define ADC_CFGR2_OVSR                      ((uint32_t)0x0000001CU)     /*!< OVSR  [2:0] bits (Oversampling ratio) */
#define ADC_CFGR2_OVSR_0                    ((uint32_t)0x00000004U)     /*!< Bit 0 */
#define ADC_CFGR2_OVSR_1                    ((uint32_t)0x00000008U)     /*!< Bit 1 */
#define ADC_CFGR2_OVSR_2                    ((uint32_t)0x00000010U)     /*!< Bit 2 */
#define ADC_CFGR2_OVSE                      ((uint32_t)0x00000001U)     /*!< Oversampler Enable */

#define ADC_BUFFER_SIZE 5
volatile uint16_t adc_buffer[ADC_BUFFER_SIZE];
volatile uint32_t adc_conversions = 0;
volatile uint32_t adc_accum[ADC_BUFFER_SIZE];

volatile uint32_t system_secs;
// The MSI at 2.1Mhz is the default startup clock speed


void sys_tick_handler(void)
{
//    gpio_toggle(LED_ERROR_PORT, LED_ERROR_PIN);

//    gpio_clear(LED_ERROR_PORT, LED_ERROR_PIN);
//    gpio_set(LED_ERROR_PORT, LED_ERROR_PIN);
//    gpio_toggle(BALANCE_PORT, BALANCE_3_PIN);

    system_secs++;
}

static void enter_sleep_mode(void) {
//    PWR_CR |= PWR_CR_PDDS;
//    SCB_SCR |= SCB_SCR_SLEEPDEEP;

   __asm__ volatile ("wfi");
}


/* Set up a timer to create 1mS ticks. */
static void systick_init(void)
{
    systick_counter_disable();

    /* clock rate / 1000 to get 1sec interrupt rate */
    systick_set_reload(rcc_ahb_frequency - 1);
    systick_set_clocksource(STK_CSR_CLKSOURCE_AHB);
    systick_clear();
    systick_counter_enable();
    systick_interrupt_enable();
}

static void delay_us(uint32_t cycles) {
    // Calculate the number of iterations needed, assuming each iteration is 10 NOPs
    uint32_t iterations = (rcc_ahb_frequency / 1000000) * cycles / 10;

    __asm__ volatile (
            "1: \n"
            "nop \n"
            "nop \n"
            "nop \n"
            "nop \n"
            "nop \n"
            "nop \n"
            "nop \n"
            "sub %[iterations], %[iterations], #1 \n"
            "cmp %[iterations], #0 \n"
            "bne 1b \n"
            : [iterations] "+r" (iterations) // Output: iterations is modified in place
    );
}


static void gpiob_init(void) {
    rcc_periph_clock_enable(RCC_GPIOB);

    // Setup the LEDs
    gpio_clear(GPIOB, LED_ERROR_PIN);
    gpio_mode_setup(GPIOB, GPIO_MODE_OUTPUT, GPIO_PUPD_NONE, LED_ERROR_PIN);

    // Setup the balance pins
    gpio_clear(BALANCE_PORT, BALANCE_1_PIN | BALANCE_2_PIN | BALANCE_3_PIN);
    gpio_mode_setup(BALANCE_PORT, GPIO_MODE_OUTPUT, GPIO_PUPD_NONE, BALANCE_1_PIN | BALANCE_2_PIN | BALANCE_3_PIN);

    // Setup the mosfet drivers output
    gpio_clear(DRIVERS_EN_PORT, DRIVERS_EN_PIN);
    gpio_mode_setup(DRIVERS_EN_PORT, GPIO_MODE_OUTPUT, GPIO_PUPD_NONE, DRIVERS_EN_PIN);
}

static void leds_init(void) {
    rcc_periph_clock_enable(RCC_TIM22);

    gpio_mode_setup(GPIOB, GPIO_MODE_AF, GPIO_PUPD_NONE, LED_ON_PIN | LED_ACTIVE_PIN);
    gpio_set_af(GPIOB, GPIO_AF4, LED_ON_PIN | LED_ACTIVE_PIN);

    // Set prescaler to 2 to get 1.05 MHz timer frequency
    timer_set_prescaler(TIM22, 2 - 1);

    // Set the period to 1000 to get a ~1 kHz PWM frequency
    timer_set_period(TIM22, 1000 - 1);

    // Configure TIM22_CH1 and TIM22_CH2 as PWM outputs
    timer_set_oc_mode(TIM22, TIM_OC1, TIM_OCM_PWM1);
    timer_set_oc_mode(TIM22, TIM_OC2, TIM_OCM_PWM1);


}

static void leds_enable(void) {
    timer_enable_oc_output(TIM22, TIM_OC1);
    timer_enable_oc_output(TIM22, TIM_OC2);

    timer_enable_counter(TIM22);
}

static void leds_disable(void) {
    timer_disable_oc_output(TIM22, TIM_OC1);
    timer_disable_oc_output(TIM22, TIM_OC2);

    timer_disable_counter(TIM22);
}

void exti0_1_isr(void) {
    // Check if the interrupt is from EXTI0
    if (exti_get_flag_status(EXTI0)) {
        // Clear the interrupt flag
        exti_reset_request(EXTI0);

        gpio_toggle(LED_ERROR_PORT, LED_ERROR_PIN);
    }
}

static void switch_init(void) {
    // Setup the switch input
    // TODO the datasheet or our calculations were wrong and the pin leakage current is higher than expected
    // So we have to use the built in pullup
    gpio_mode_setup(SWITCH_PORT, GPIO_MODE_INPUT, GPIO_PUPD_PULLUP, SWITCH_PIN);

    rcc_periph_clock_enable(RCC_SYSCFG);

    // Select the source input for EXTI0
    exti_select_source(EXTI0, SWITCH_PORT);

    // Configure EXTI0 to trigger on falling edge
    exti_set_trigger(EXTI0, EXTI_TRIGGER_FALLING);

    // Enable EXTI0 interrupt
    exti_enable_request(EXTI0);

    // Enable the EXTI0 interrupt in the NVIC
    nvic_enable_irq(NVIC_EXTI0_1_IRQ);
}


//void dma1_channel1_isr(void)
//{
//    if (dma_get_interrupt_flag(DMA1, DMA_CHANNEL1, DMA_TCIF)) {
//        dma_clear_interrupt_flags(DMA1, DMA_CHANNEL1, DMA_TCIF);
//        gpio_toggle(LED_ERROR_PORT, LED_ERROR_PIN);
//    }
//}

static volatile bool adc_conversion_finished = false;

void adc_comp_isr(void)
{
    if (adc_eos(ADC1)) {
        ADC_ISR(ADC1) = ADC_ISR_EOS;
        adc_conversion_finished = true;

        for (uint8_t i = 0; i < ADC_BUFFER_SIZE; i++) {
            adc_accum[i] += adc_buffer[i];
        }
        adc_conversions++;
    }

//    __asm__ volatile (
//        // gpio_set(LED_ERROR_PORT, LED_ERROR_PIN)
//            "LDR R0, =%[port_bsrr]\n\t"               // Load the address of LED_ERROR_PORT into R0
//            "LDR R1, =%[pin]\n\t"                // Load the value of LED_ERROR_PIN into R1
//            "STR R1, [R0, #24]\n\t"                   // Store the value of LED_ERROR_PIN at the address in R0 (LED_ERROR_PORT)
//
//            // if (adc_eos(ADC1))
//            "LDR R2, =%[adc]\n\t"                // Load the address of ADC1 into R2
//            "LDR R3, [R2, #0x00]\n\t"            // Load the ADC_ISR register value at ADC1 into R3
//            "LDR R4, =%[eos]\n\t"                // Load the value of ADC_ISR_EOS into R4
//            "TST R3, R4\n\t"                     // Test if EOS bit is set
//            "BEQ 1f\n\t"                         // Branch to label 1 if EOS bit is not set
//            "STR R4, [R2, #0x00]\n\t"            // Store the value of ADC_ISR_EOS into ADC_ISR register
//
//            // adc_conversion_finished = true
//            "LDR R5, =%[conversion_finished]\n\t" // Load the address of adc_conversion_finished into R5
//            "MOVS R6, #1\n\t"                     // Load the value 1 into R6 (true)
//            "STRB R6, [R5]\n\t"                   // Store the value 1 into adc_conversion_finished
//
//            // adc_conversions++
//            "LDR R7, =%[conversions]\n\t"         // Load the address of adc_conversions into R7
//            "LDR R6, [R7]\n\t"                    // Load the current value of adc_conversions into R6
//            "ADD R6, R6, #1\n\t"                  // Increment the value in R6 by 1
//            "STR R6, [R7]\n\t"                    // Store the incremented value back to adc_conversions
//
//            // Increment the accums
//            "LDR R6, =adc_accum\n"     // Load address of adc_accum
//            "LDR R7, =adc_buffer\n"    // Load address of adc_buffer
//
//            "LDRH R1, [R7, #0]\n"      // Load adc_buffer[0]
//            "LDR R2, [R6, #0]\n"      // Load adc_accum[0]
//            "ADD R1, R1, R2\n"        // Add values
//            "STR R1, [R6, #0]\n"      // Store result back to adc_accum[0]
//
//            "LDRH R1, [R7, #2]\n"      // Load adc_buffer[0]
//            "LDR R2, [R6, #4]\n"      // Load adc_accum[0]
//            "ADD R1, R1, R2\n"        // Add values
//            "STR R1, [R6, #4]\n"      // Store result back to adc_accum[1]
//
//            "LDRH R1, [R7, #4]\n"      // Load adc_buffer[0]
//            "LDR R2, [R6, #8]\n"      // Load adc_accum[0]
//            "ADD R1, R1, R2\n"        // Add values
//            "STR R1, [R6, #8]\n"      // Store result back to adc_accum[2]
//
//            // gpio_clear(LED_ERROR_PORT, LED_ERROR_PIN)
//            "1:\n\t"
//            "LDR R0, =%[port_bsrr]\n\t"               // Load the address of LED_ERROR_PORT into R0
//            "LDR R1, =%[pin]\n\t"                // Load the value of LED_ERROR_PIN into R1
//            "LSL R1, R1, #16\n\t"
//            "STR R1, [R0, #24]\n\t"               // Clear the value of LED_ERROR_PIN at the address in R0+4 (LED_ERROR_PORT)
//            :
//            : [port_bsrr] "i" (LED_ERROR_PORT), [pin] "i" (LED_ERROR_PIN),
//    [adc] "i" (ADC1), [eos] "i" (ADC_ISR_EOS),
//    [conversion_finished] "i" (&adc_conversion_finished), [conversions] "i" (&adc_conversions),
//    [adc_accum] "i" (adc_accum), [adc_buffer] "i" (adc_buffer)
//    : "r0", "r1", "r2", "r3", "r4", "r5", "r6", "r7"
//    );
}

static void adc_init(void) {
    rcc_periph_clock_enable(RCC_ADC1);
    rcc_periph_clock_enable(RCC_GPIOA);
    rcc_periph_clock_enable(RCC_DMA);

    ADC_CCR(ADC1) |= ADC_CCR_LFMEN;
    ADC_CFGR2(ADC1) |= ADC_CFGR2_CKMODE_PCLK;

    gpio_mode_setup(VSOLAR_ADC_PORT, GPIO_MODE_ANALOG, GPIO_PUPD_NONE, VSOLAR_ADC_PIN);
    gpio_mode_setup(VBATT_ADC_PORT, GPIO_MODE_ANALOG, GPIO_PUPD_NONE, VBATT_ADC_PIN);
    gpio_mode_setup(SOLAR_CURRENT_ADC_PORT, GPIO_MODE_ANALOG, GPIO_PUPD_NONE, SOLAR_CURRENT_ADC_PIN);

    gpio_mode_setup(ADC_MULTIPLEX_PORT, GPIO_MODE_OUTPUT, GPIO_PUPD_NONE, ADC_MULTIPLEX_CELL4V_PIN | ADC_MULTIPLEX_CELL8V_PIN | ADC_MULTIPLEX_VBATT_PIN);

    adc_power_off(ADC1);
    adc_calibrate(ADC1);
    adc_set_right_aligned(ADC1);
    adc_set_resolution(ADC1, ADC_CFGR1_RES_12_BIT);
    adc_set_single_conversion_mode(ADC1);


    adc_power_on(ADC1);
}

static void adc_set_oversample_256(bool oversample) {
    // Configure oversampling
    // Oversampling can only be configured if the adc is off
    if (!!oversample != !!(ADC_CFGR2(ADC1) & ADC_CFGR2_OVSS)) {
        printf("adc restart\n");

        adc_power_off(ADC1);

        ADC_CFGR2(ADC1) &= ~ADC_CFGR2_OVSS;
        ADC_CFGR2(ADC1) &= ~ADC_CFGR2_OVSR;

        if (oversample) {
            ADC_CFGR2(ADC1) |= ADC_CFGR2_OVSR_0 | ADC_CFGR2_OVSR_1 | ADC_CFGR2_OVSR_2; // 256x oversampling
            ADC_CFGR2(ADC1) |= ADC_CFGR2_OVSS_3; // Divide by 256 afterwards;
            ADC_CFGR2(ADC1) |= ADC_CFGR2_OVSE;
        } else {
            ADC_CFGR2(ADC1) &= ~ADC_CFGR2_OVSE;
        }

        adc_power_on(ADC1);
    }
}

static void adc_start_conversion_dma(uint32_t channel_mask, bool oversample) {
    // Set the sample rate
    ADC_SMPR1(ADC1) = ADC_SMPR_SMP_160DOT5CYC;

    // Select which channels to read
    ADC_CHSELR(ADC1) = channel_mask;

    adc_set_oversample_256(oversample);

    // ADC DMA
    dma_channel_reset(DMA1, DMA_CHANNEL1);
    dma_set_peripheral_address(DMA1, DMA_CHANNEL1, (uint32_t)&ADC_DR(ADC1));
    dma_set_memory_address(DMA1, DMA_CHANNEL1, (uint32_t)adc_buffer);
    dma_set_number_of_data(DMA1, DMA_CHANNEL1, ADC_BUFFER_SIZE);
    dma_set_read_from_peripheral(DMA1, DMA_CHANNEL1);
    dma_enable_memory_increment_mode(DMA1, DMA_CHANNEL1);
    dma_set_peripheral_size(DMA1, DMA_CHANNEL1, DMA_CCR_PSIZE_16BIT);
    dma_set_memory_size(DMA1, DMA_CHANNEL1, DMA_CCR_MSIZE_16BIT);
    dma_set_priority(DMA1, DMA_CHANNEL1, DMA_CCR_PL_HIGH);
    dma_enable_channel(DMA1, DMA_CHANNEL1);

    // Clear end of sequence flag
    adc_conversion_finished = false;

    // Enable interrupt for testing
    ADC_IER(ADC1) |= ADC_IER_EOSIE;
    nvic_enable_irq(NVIC_ADC_COMP_IRQ);


    adc_disable_dma_circular_mode(ADC1);
    adc_enable_dma(ADC1);

    // Start converting in a loop into the buffer
    adc_start_conversion_regular(ADC1);
}
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
int main(void) {
    gpiob_init();
    leds_init();
    systick_init();
    usart_comm_init();
    switch_init();

    adc_init();
    buck_boost_init();


    // Sleep mode tests
    rcc_periph_clock_enable(RCC_PWR);
    pwr_disable_backup_domain_write_protect();

    // Lowest possible internal voltage scaling to save power, limits to 4mhz clock
    pwr_set_vos_scale(PWR_SCALE3);

//    while(1) {
//        enter_sleep_mode();
//    }

    printf("startup\n");


    while (1) {
        if (cur_state == STATE_STARTUP) {
            // Give one second to startup, so all voltages can stabilize
            if (system_secs > 1) {
                change_state(STATE_START_SAMPLE);
                //change_state(STATE_START_CHARGE);
            }
        } else if (cur_state == STATE_START_SAMPLE) {
            gpio_clear(ADC_MULTIPLEX_PORT, ADC_MULTIPLEX_VBATT_PIN | ADC_MULTIPLEX_CELL4V_PIN | ADC_MULTIPLEX_CELL8V_PIN);
            cur_sample_channel = 0;

            change_state(STATE_SELECT_SAMPLE_MULTIPLEXER);
        } else if (cur_state == STATE_SELECT_SAMPLE_MULTIPLEXER) {
            if (cur_sample_channel == 0) {
                adc_enable_vrefint();
            }
            else if (cur_sample_channel == 1) {
                adc_disable_vrefint();
                gpio_clear(ADC_MULTIPLEX_PORT, ADC_MULTIPLEX_VBATT_PIN | ADC_MULTIPLEX_CELL4V_PIN | ADC_MULTIPLEX_CELL8V_PIN);
                delay_us(2000); // Need to wait for the multiplexer to switch off the previous voltage or else you'll have two enabled at the same time which shows a distinct current spike
                gpio_set(ADC_MULTIPLEX_PORT, ADC_MULTIPLEX_VBATT_PIN);
            }
            else if (cur_sample_channel == 2) {
                gpio_clear(ADC_MULTIPLEX_PORT, ADC_MULTIPLEX_VBATT_PIN | ADC_MULTIPLEX_CELL4V_PIN | ADC_MULTIPLEX_CELL8V_PIN);
                delay_us(2000); // Need to wait for the multiplexer to switch off the previous voltage or else you'll have two enabled at the same time which shows a distinct current spike
                gpio_set(ADC_MULTIPLEX_PORT, ADC_MULTIPLEX_CELL4V_PIN);
            }
            else if (cur_sample_channel == 3) {
                gpio_clear(ADC_MULTIPLEX_PORT, ADC_MULTIPLEX_VBATT_PIN | ADC_MULTIPLEX_CELL4V_PIN | ADC_MULTIPLEX_CELL8V_PIN);
                delay_us(2000); // Need to wait for the multiplexer to switch off the previous voltage or else you'll have two enabled at the same time which shows a distinct current spike
                gpio_set(ADC_MULTIPLEX_PORT, ADC_MULTIPLEX_CELL8V_PIN);
            }
            else if (cur_sample_channel == 4) {
                gpio_clear(ADC_MULTIPLEX_PORT, ADC_MULTIPLEX_VBATT_PIN | ADC_MULTIPLEX_CELL4V_PIN | ADC_MULTIPLEX_CELL8V_PIN);
            }


            change_state(STATE_WAIT_SAMPLE_MULTIPLEXER);
        } else if (cur_state == STATE_WAIT_SAMPLE_MULTIPLEXER) {
            delay_us(5000);

            if (cur_sample_channel == 0 )
                adc_start_conversion_dma(ADC_CHSELR_CHSEL(VREFINT_ADC_CH), true);
            else if (cur_sample_channel >= 1 && cur_sample_channel <= 3)
                adc_start_conversion_dma(ADC_CHSELR_CHSEL(VBATT_ADC_CH), true);
            else if (cur_sample_channel == 4)
                adc_start_conversion_dma(ADC_CHSELR_CHSEL(VSOLAR_ADC_CH), true);

            change_state(STATE_WAIT_SAMPLE);
        } else if (cur_state == STATE_WAIT_SAMPLE) {
            if (adc_conversion_finished){
                if (cur_sample_channel == 0) {
                    cur_vrefint = adc_buffer[0];

                    cur_sample_channel++;
                    change_state(STATE_SELECT_SAMPLE_MULTIPLEXER);
                }
                else if (cur_sample_channel == 1) {
                    cur_vbatt = (adc_buffer[0] * VDDA_CONVERSION_RATIO_NUM * VREFINT_CAL) / (VDDA_CONVERSION_RATIO_DEN * cur_vrefint);

                    cur_sample_channel++;
                    change_state(STATE_SELECT_SAMPLE_MULTIPLEXER);
                }
                else if (cur_sample_channel == 2) {
                    cur_4v = (adc_buffer[0] * VDDA_CONVERSION_RATIO_NUM * VREFINT_CAL) / (VDDA_CONVERSION_RATIO_DEN * cur_vrefint);

                    cur_sample_channel++;
                    change_state(STATE_SELECT_SAMPLE_MULTIPLEXER);
                }
                else if (cur_sample_channel == 3) {
                    cur_8v = (adc_buffer[0] * VDDA_CONVERSION_RATIO_NUM * VREFINT_CAL) / (VDDA_CONVERSION_RATIO_DEN * cur_vrefint);

                    cur_sample_channel++;
                    change_state(STATE_SELECT_SAMPLE_MULTIPLEXER);
                }
                else if (cur_sample_channel == 4) {
                    cur_vsolar = (adc_buffer[0] * VDDA_CONVERSION_RATIO_NUM * VREFINT_CAL) / (VDDA_CONVERSION_RATIO_DEN * cur_vrefint);

                    cur_sample_channel++;
                    change_state(STATE_SAMPLE);
                }
            } else {
                enter_sleep_mode();
            }
        } else if (cur_state == STATE_SAMPLE) {
            printf("sample %d %d %d %d %d %d\n", cur_vbatt, cur_8v, cur_4v, cur_vsolar, cur_vrefint, VREFINT_CAL);

            uint16_t cell1 = cur_4v;
            uint16_t cell2 = cur_8v - cur_4v;
            uint16_t cell3 = cur_vbatt - cur_8v;

            if (cur_vbatt < VBATT_LOW_THRESHOLD) {
                printf("low vbatt %d\n", cur_vbatt);
                change_state(STATE_LOW_BATT_SLEEP);
            }
            else if (cell1 < SINGLE_CELL_LOW_THRESHOLD) {
                printf("low cell_1 %d\n", cell1);
                change_state(STATE_LOW_BATT_SLEEP);
            } else if (cell2< SINGLE_CELL_LOW_THRESHOLD) {
                printf("low cell_2 %d\n", cell2);
                change_state(STATE_LOW_BATT_SLEEP);
            } else if (cell3 < SINGLE_CELL_LOW_THRESHOLD) {
                printf("low cell_3 %d\n",cell3);
                change_state(STATE_LOW_BATT_SLEEP);
            } else if (cur_vsolar > VSOLAR_START_CHARGING_THRESHOLD && cur_vbatt < VBATT_MAX_THRESHOLD) {
                change_state(STATE_START_CHARGE);
            } else if (system_secs - last_balance_check > 60) {
                printf("balance %d %d %d\n", cell1, cell2, cell3);
                last_balance_check = system_secs;

                if (cell1 > cell2 && cell1 > cell3 &&
                    ((cell1 - cell2) > MIN_BALANCE_DIFF_THRESHOLD || (cell1 - cell3) > MIN_BALANCE_DIFF_THRESHOLD)) {
                    change_state(STATE_BALANCE);
                    cur_balance_cell = 1;
                } else if (cell2 > cell1 && cell2 > cell3 &&
                           ((cell2 - cell1) > MIN_BALANCE_DIFF_THRESHOLD || (cell2 - cell3) > MIN_BALANCE_DIFF_THRESHOLD)) {
                    change_state(STATE_BALANCE);
                    cur_balance_cell = 2;
                } else if (cell3 > cell1 && cell3 > cell2 &&
                           ((cell3 - cell1) > MIN_BALANCE_DIFF_THRESHOLD || (cell3 - cell2) > MIN_BALANCE_DIFF_THRESHOLD)) {
                    change_state(STATE_BALANCE);
                    cur_balance_cell = 3;
                } else {
                    change_state(STATE_NORMAL_SLEEP);
                }
            }
            else {
                change_state(STATE_NORMAL_SLEEP);
            }

            // Be sure the multiplexer is off when leaving this state
            gpio_clear(ADC_MULTIPLEX_PORT, ADC_MULTIPLEX_VBATT_PIN | ADC_MULTIPLEX_CELL4V_PIN | ADC_MULTIPLEX_CELL8V_PIN);
        } else if (cur_state == STATE_LOW_BATT_SLEEP) {
            //gpio_set(LED_ERROR_PORT, LED_ERROR_PIN);

            enter_sleep_mode();

            if (system_secs - cur_state_start_secs > 30) {
                change_state(STATE_START_SAMPLE);
            }
        } else if (cur_state == STATE_NORMAL_SLEEP) {
            enter_sleep_mode();

            if (system_secs - cur_state_start_secs > 2) {
                change_state(STATE_START_SAMPLE);
            }
        } else if (cur_state == STATE_START_CHARGE) {
            // Set the multiplexer to be measuring VBATT on future conversions
            gpio_clear(ADC_MULTIPLEX_PORT, ADC_MULTIPLEX_VBATT_PIN | ADC_MULTIPLEX_CELL4V_PIN | ADC_MULTIPLEX_CELL8V_PIN);
            gpio_set(ADC_MULTIPLEX_PORT, ADC_MULTIPLEX_VBATT_PIN);

            // Enable the drivers
            gpio_set(DRIVERS_EN_PORT, DRIVERS_EN_PIN);

            // Get a baseline of the solar current, so you can zero-out the sensor properly
            adc_start_conversion_dma(ADC_CHSELR_CHSEL(SOLAR_CURRENT_ADC_CH), true);
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

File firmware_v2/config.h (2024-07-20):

#ifndef CONFIG_H
#define CONFIG_H

#define USART1_BAUDRATE 115200

#define BUCK_BOOST_PERIOD 200
#define BUCK_BOOST_AVERAGE_SAMPLES 5000

#define VOLTAGE_TO_VBATT_ADC(voltage) ((int)((voltage) * 4095 * 1600 / (2.5 * (7575 + 1600)) + 0.5))
#define VBATT_ADC_TO_VOLTAGE(adc) (((adc) - 0.5) * (2.5 * (7575 + 1600)) / (4095 * 1600))

#define VOLTAGE_TO_VSOLAR_ADC(voltage) ((int)((voltage) * 4095 * 2 / (2.5 * (18.0 + 2.0)) + 0.5))
#define VSOLAR_ADC_TO_VOLTAGE(adc) (((adc) - 0.5) * (2.5 * (18.0 + 2.0)) / (4095 * 2.0))

// An approximation to VOLTAGE_TO_VSOLAR_ADC(1) / VOLTAGE_TO_VBATT_ADC(1)
#define VSOLAR_TO_VBATT_RATIO_NUM 100
#define VSOLAR_TO_VBATT_RATIO_DEN 57

#define VREFINT_CAL MMIO16(0x1FF80078)

#define VDDA_DATASHEET_VOLTAGE (3.0)
// This is the ratio between our own 2.5V and the 3V that the ADC was calibrated at
#define VDDA_CONVERSION_RATIO_NUM 6
#define VDDA_CONVERSION_RATIO_DEN 5


// Based on 1.2V per amp
#define ADC_TO_CURRENT(adc_value) (((adc_value) * 2.5 / 4095) / 1.2)
#define CURRENT_TO_ADC(current) ((uint16_t)(((current) * 1.2 / 2.5) * 4095))

#define MAX_SOLAR_POWER 500000

#define SINGLE_CELL_LOW_THRESHOLD VOLTAGE_TO_VBATT_ADC(3.6f)
#define SINGLE_CELL_NOT_PRESENT_THRESHOLD VOLTAGE_TO_VBATT_ADC(0.15f)
#define VBATT_LOW_THRESHOLD VOLTAGE_TO_VBATT_ADC(11.0f)
#define VBATT_MAX_THRESHOLD VOLTAGE_TO_VBATT_ADC(12.1f)

#define VSOLAR_START_CHARGING_THRESHOLD VOLTAGE_TO_VSOLAR_ADC(15.0f)
#define VSOLAR_STOP_CHARGING_THRESHOLD VOLTAGE_TO_VSOLAR_ADC(10.0f)

// If we are measuring anything too close to 4095, which is the max, then we should just shutdown
#define VSOLAR_MEASUREMENT_ERROR_THRESHOLD 4090

#define MIN_BALANCE_DIFF_THRESHOLD VOLTAGE_TO_VBATT_ADC(0.1f)

#endif

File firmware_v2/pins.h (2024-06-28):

#ifndef PINS_H
#define PINS_H

#define USART1_PORT GPIOA
#define USART1_TX_PIN GPIO9
#define USART1_RX_PIN GPIO10

#define BALANCE_PORT GPIOB
#define BALANCE_1_PIN GPIO7
#define BALANCE_2_PIN GPIO8
#define BALANCE_3_PIN GPIO9

#define LED_ON_PORT GPIOB
#define LED_ON_PIN GPIO4

#define LED_ACTIVE_PORT GPIOB
#define LED_ACTIVE_PIN GPIO5

#define LED_ERROR_PORT GPIOB
#define LED_ERROR_PIN GPIO6

#define VSOLAR_ADC_PORT GPIOA
#define VSOLAR_ADC_PIN GPIO0
#define VSOLAR_ADC_CH 0

#define VBATT_ADC_PORT GPIOA
#define VBATT_ADC_PIN GPIO1
#define VBATT_ADC_CH 1

#define SOLAR_CURRENT_ADC_PORT GPIOA
#define SOLAR_CURRENT_ADC_PIN GPIO2
#define SOLAR_CURRENT_ADC_CH 2

#define TEMP_SENSOR_ADC_CH 18
#define VREFINT_ADC_CH 17

#define ADC_MULTIPLEX_PORT GPIOA
#define ADC_MULTIPLEX_CELL4V_PIN GPIO5
#define ADC_MULTIPLEX_CELL8V_PIN GPIO6
#define ADC_MULTIPLEX_VBATT_PIN GPIO7

#define SWITCH_PORT GPIOB
#define SWITCH_PIN GPIO0

#define DRIVERS_EN_PORT GPIOB
#define DRIVERS_EN_PIN GPIO1

#define BB_SW_A_PORT GPIOA
#define BB_SW_A_PIN GPIO15

#define BB_D_A_PORT GPIOB
#define BB_D_A_PIN GPIO3

#define BB_SW_B_PORT GPIOB
#define BB_SW_B_PIN GPIO10

#define BB_D_B_PORT GPIOB
#define BB_D_B_PIN GPIO11


#endif

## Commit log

2024-04-18 Many stages done
    [JPBms2.kicad_pcb, JPBms2.kicad_sch, buckboost.kicad_sch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]
2024-04-18 removing old
    [untitled.kicad_sch]
2024-04-18 Some part selections
    [JPBms2.kicad_pcb, JPBms2.kicad_sch, buckboost.kicad_sch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]
2024-04-20 Connect adc
    [buckboost.kicad_sch, mcu.kicad_sch]
2024-04-21 Starting to do layout
    [JPBms2.kicad_pcb]
2024-04-24 Adding simple balance circuits
    [JPBms2.kicad_pcb, JPBms2.kicad_sch, balance.kicad_sch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]
2024-04-26 Smaller diodes, more work
    [JPBms2.kicad_pcb, balance.kicad_sch, mcu.kicad_sch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]
2024-04-26 Some more placement
    [JPBms2.kicad_pcb, balance.kicad_sch]
2024-04-26 More layout adust
    [JPBms2.kicad_pcb, buckboost.kicad_sch, power.kicad_sch]
2024-04-27 Routing more
    [JPBms2.kicad_pcb, buckboost.kicad_sch]
2024-05-03 Layout done
    [JPBms2.kicad_pcb]
2024-05-03 bom pt1
    [JPBms2.kicad_pcb, mcu.kicad_sch, power.kicad_sch]
2024-05-06 Assigning PNs
    [JPBms2.kicad_pcb, balance.kicad_sch, buckboost.kicad_sch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]
2024-05-06 slight changes
    [JPBms2.kicad_pcb, JPBms2.kicad_sch, balance.kicad_sch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]
2024-05-06 sent to jlcpcb
    [balance.kicad_sch, mcu.kicad_sch, power.kicad_sch]
2024-05-14 Schematics updated P mosfets
    [balance.kicad_sch, buckboost.kicad_sch]
2024-05-14 New design and layout
    [JPBms2.kicad_pcb, balance.kicad_sch, buckboost.kicad_sch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]
2024-05-15 Finishing layout
    [JPBms2.kicad_pcb]
2024-05-15 Better balance resistors, fixes
    [JPBms2.kicad_pcb, balance.kicad_sch, buckboost.kicad_sch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]
2024-05-15 N fets
    [JPBms2.kicad_pcb, buckboost.kicad_sch]
2024-05-15 V1.1 spin
    [JPBms2.kicad_pcb, mcu.kicad_sch]
2024-05-15 V1.1 gerbers made
    [JPBms2-B_Cu.gbl, JPBms2-B_Mask.gbs, JPBms2-B_Paste.gbp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]
2024-05-21 Notes for v2
    [JPBms2.kicad_pcb]
2024-05-22 Adding notes, committing firmware to repo
    [JPBms2.kicad_pcb]
2024-05-22 Added plugged in detection
    [JPBms2.kicad_pcb, mcu.kicad_sch, power.kicad_sch]
2024-05-22 Uart working
    [JPBms2.kicad_pcb]
2024-05-22 More notes
    [JPBms2.kicad_pcb]
2024-05-22 Adding a few notes, adding detection on solar and uart plugs
    [JPBms2.kicad_pcb, buckboost.kicad_sch, mcu.kicad_sch]
2024-05-22 Adding flow chart to main.c Adding leds on balancers
    [balance.kicad_sch, mcu.kicad_sch]
2024-05-24 Fixing up state machine, inductor circuit working better
    [main.c]
2024-05-24 Adding notes
    [JPBms2.kicad_pcb]
2024-05-25 Save power with usart, add oversampling support when balancing to get better reading, add notes on pcb
    [JPBms2.kicad_pcb, mcu.kicad_sch]
2024-05-26 Adding notes, solder jumpers for picking polarity of dc plugs
    [JPBms2.kicad_pcb, power.kicad_sch]
2024-05-28 Adding XT30 solar connector
    [JPBms2.kicad_pcb, adc.kicad_sch, power.kicad_sch]
2024-05-28 Adding switch, moving current sense
    [JPBms2.kicad_pcb, mcu.kicad_sch, power.kicad_sch]
2024-05-28 Starting draft of ADC multiplexer
    [JPBms2.kicad_pcb, adc.kicad_sch, balance.kicad_sch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]
2024-05-28 Adding ADC multiplexer, protection diodes
    [JPBms2.kicad_pcb, adc.kicad_sch, balance.kicad_sch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]
2024-05-28 Moving balance resistors to make more sense
    [JPBms2.kicad_pcb]
2024-05-29 Adding new ST driver, protecting uart input
    [JPBms2.kicad_pcb, buckboost.kicad_sch, mcu.kicad_sch]
2024-05-29 Basic charging code, stupid power connector was reversed
    [power.kicad_sch]
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2024-05-30 Code cleanup, notes on gate oscillations
    [main.c, usart.c]
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2024-06-04 Fix for adc trigger, but it's still not going continuously
    [main.c]
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2024-06-07 Taking notes, doing some final adjustments to RC filter values
    [JPBms2.kicad_pcb, adc.kicad_sch, buckboost.kicad_sch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]
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2024-06-07 L6388E mosfet drivers
    Allow to enable/disable drivers
    voltage dividers picked out
    [JPBms2.kicad_pcb, adc.kicad_sch, buckboost.kicad_sch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]
2024-06-07 New schematic done
    [JPBms2.kicad_sch, adc.kicad_sch, balance.kicad_sch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]
2024-06-08 A couple of part selections
    [JPBms2.kicad_pcb, adc.kicad_sch, buckboost.kicad_sch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]
2024-06-09 Decent pass
    [JPBms2.kicad_pcb, adc.kicad_sch, balance.kicad_sch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]
2024-06-09 Routing pt1
    [JPBms2.kicad_pcb, adc.kicad_sch, balance.kicad_sch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]
2024-06-10 More routing
    [JPBms2.kicad_pcb]
2024-06-10 94 unrouted
    [JPBms2.kicad_pcb, mcu.kicad_sch]
2024-06-10 35 left
    [JPBms2.kicad_pcb]
2024-06-10 17 left
    [JPBms2.kicad_pcb]
2024-06-10 It is routed
    [JPBms2.kicad_pcb]
2024-06-10 Fine tuning routing
    [JPBms2.kicad_pcb]
2024-06-10 Better thermal pads
    [JPBms2.kicad_pcb]
2024-06-10 Starting cleanup
    [JPBms2.kicad_pcb, buckboost.kicad_sch]
2024-06-10 Some label cleanup, but it's a packed board
    [JPBms2.kicad_pcb]
2024-06-10 V1.2 production
    [BOM-JPBms2.csv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]
2024-06-19 Adding button support, changing the sample stuff to match the new schematics, new pin defintions, first few v1.3 ideas
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2024-06-20 Labeling balance leds properly
    [JPBms2.kicad_pcb]
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2024-06-25 Making notes, voltage controlled MPPT now works better, more efficient low side during charge phase
    [JPBms2.kicad_pcb]
2024-06-29 More accurate VBATT resistors, recalibrated vbatt off of vrefint, getting 0.5% accurate readings now
    [JPBms2.kicad_pcb, adc.kicad_sch]
2024-07-06 Board 1.3 ready -> fixed comparator inputs, balance LEDs, and TVS diode for battery disconnect protection
    [JPBms2.kicad_pcb, buckboost.kicad_sch, mcu.kicad_sch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]
2024-07-08 v1.3 JLCPCB production
    [BOM-JPBms2.csv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]
2024-07-08 Adding an LCSC code, should have been obvious though
    [mcu.kicad_sch, power.kicad_sch]
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2024-07-20 V1.3 getting ready to show some friends
    [BOM-JPBms2.csv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]
